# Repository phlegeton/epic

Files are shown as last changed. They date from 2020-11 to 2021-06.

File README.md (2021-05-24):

# The Extensible PI Cluster Frame  
This repository contains all the files for the The Extensible PI Cluster Frame  or **EPIC Frame**  

This cluster frame provides:

* Easy way if extending the frame
* Easy way of inserting / removing PI nodes from the cluster frame
* Each node can have proper cooling, by able to place heat-sinks on the PI nodes. 
* A special developed PI Cluster HAT provides addition cooling by PWM controlled FAN 
* A special developed PI Cluster HAT provides signal distribution across a backplane (Power 3.3V,5V,I2C)
* A special developed backplane provides power and signal (I2C) to each node
* A special developed LED board provides 3 RGB LED per node for status
* A special developed Power board provides the interface to the backplane 
* The cluster frame is extensible. The smallest frame consist of two nodes, and can be extended by 2 nodes (2,4,8,10)
* A Frame of 10 PI nodes fits into a 19" rack.

This cluster frame needs an external power supply. See the documentation directory for more information about power requirements.

This repository contains all the files to create the Cluster frame and PCB's. See the docs directory for more information and installation instructions.
In the tools directory you find tools which may be handy during assembly.

Note that:

**Current this project is in active development** 
which means that:

The design is still changing, and there are still changes being made. 

If you however want to help, and test things out or just want to give feedback:

Then **YES** put your 3D printer to work and test out the design!

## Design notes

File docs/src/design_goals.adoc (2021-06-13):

////
:imagesdir: assets/images 
:includesdir: include
include::./{includesdir}/document_settings.adoc[]
////
== Design goals
The cluster frame is designed with the idea of being as modulair as possible. This means that the minimal frame size is just for 2 nodes. This frame can then easily be extended into 4,6,8 or 10 pi's max if the frame needs to be 19" mountable. It's easy to stack 10 rows on Pi's in a rack. When extending the frame to more then 10 Pi's I'm not sure if the frame is strong enough to do this. 

That brings me to the second design goal: The whole design needs to be free to everyone who wants to build it, and it must be possible for everyone to adjust it to one needs. 

So this frame is ideal if you want to stack some PI's together. However if you need access to the GPIO pins, this frame might not be for you. The  GPIO pins are covered by a HAT which enables the PI cluster node to have proper cooling, and allows for three RGB leds. This frame intended use is for housing a PI cluster. And normally in a cluster setup the GPIO pins are not used. (in this case some of them are, for controlling RGB status LED's and a FAN for cooling).

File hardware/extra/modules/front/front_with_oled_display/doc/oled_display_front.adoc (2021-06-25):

== Installing the OLED front Display
The OLED display front can be attached to the PI tray in the same way as the original front. The OLED display to use is: OLED Display 0,91 inch 128x32 with a SSD1306 driver. This allows the use of the Adafruit OLED library for the Raspberry pi. 

To connect the display connector J5 can be used. The connections are: 

* pin 1 GND
* pin 2 3.3V
* pin3 SCL
* pin4 SDA

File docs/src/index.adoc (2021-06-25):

:toc:
:toc-placement!: 
= Extensible PI Cluser Frame - Hardware guide
Hades <hades@spacebugs.nl>
v1.0, 2020-28-11
//include::./{includesdir}/document_settings.adoc[]

//include::./include/documents_settings.adoc[]
include::include/document_settings.adoc[]

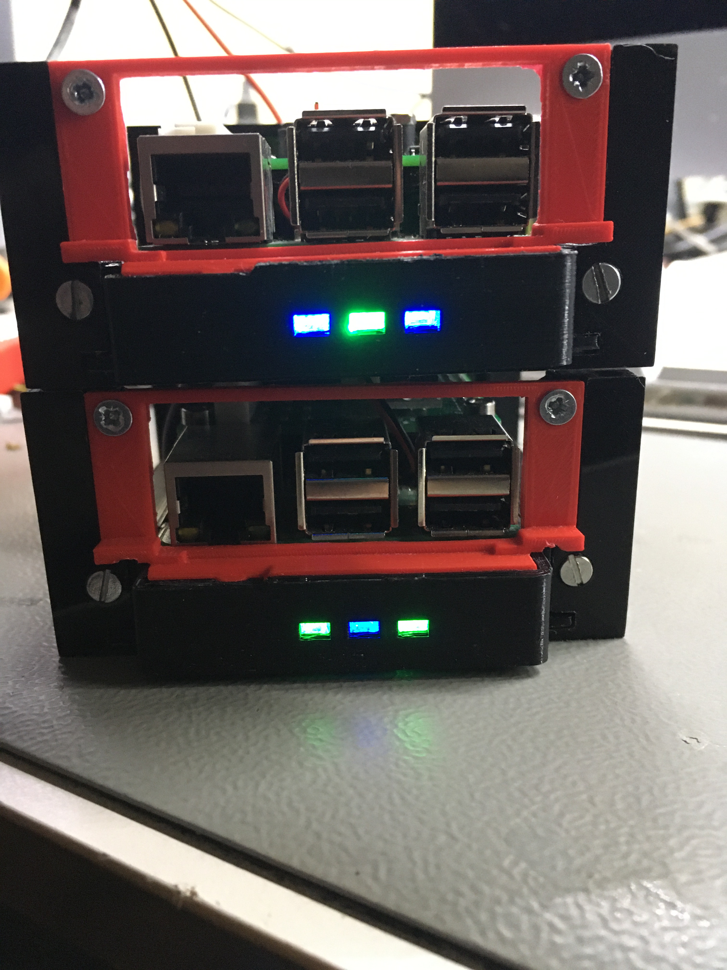
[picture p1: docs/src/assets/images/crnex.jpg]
Two node cluster


== Main index

toc::[]

include::introduction.adoc[]

include::a_word_about_license.adoc[]

include::design_goals.adoc[]

include::current_issues.adoc[]

include::roadmap.adoc[]

include::modules.adoc[]

include::3d_printing_the_parts.adoc[]

include::preparing_pi_tray.adoc[]

include::assemble_front_panel_with_bezel.adoc[]

include::Features_power_board.adoc[]

include::assemble_power_board.adoc[]

include::Features_PI_Cluster_hat.adoc[]

include::assemble_cluster_hat.adoc[]

include::Features_LED_board.adoc[]

include::assemble_led_board.adoc[]

include::assemble_pi_tray.adoc[]

include::building_cluster_frame.adoc[]

include::attach_backplane_cover.adoc[]

include::testing_pi_cluster_frame.adoc[]

include::parts_list_introduction.adoc[]

include::complete_parts_list.adoc[]

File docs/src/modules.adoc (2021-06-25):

== Modules
The whole design idea is to have a modular design. In the repository under the extra directory there is a modules directory. Currently only a front-end module exist. The idea of this directory is that its possible to add "third party" modules. For example it could be possible that someone comes up with parts for an alternative cluster frame. The modules directory can be used to place these modules. Which means the rest of the original cluster frame in the repository can be left untouched.

Each module directory must include a doc directory, explaining how to use / build etc. 

The current alternative front-end module allows one to add a oled display to the front-end instead of the RGB leds.

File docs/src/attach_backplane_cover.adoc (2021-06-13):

////
:imagesdir: assets/images 
:includesdir: include
include::./{includesdir}/document_settings.adoc[]
////

== Attaching the backplane cover
If the cluster frame is able to power all the PI nodes, the back-plane covers can be placed.

To attach the back-plane cover you need: 

- 1x XT60 connector 
- 2x M2.5x10
- For every back-plane you need one cover
- For every back-plane cover you need 4x M3x40 screw

=== Prepare the back-plane cover
One of the back-plane cover is holding the XT60 connector, so there is one 5V connection which powers the whole PI cluster: 

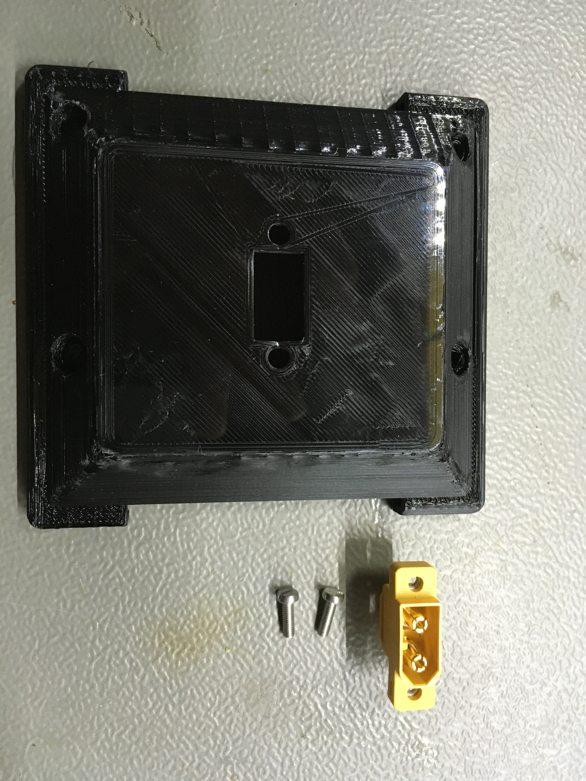
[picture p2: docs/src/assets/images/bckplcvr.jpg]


To attach the XT60 connector insert the XT60 connector from the back:  

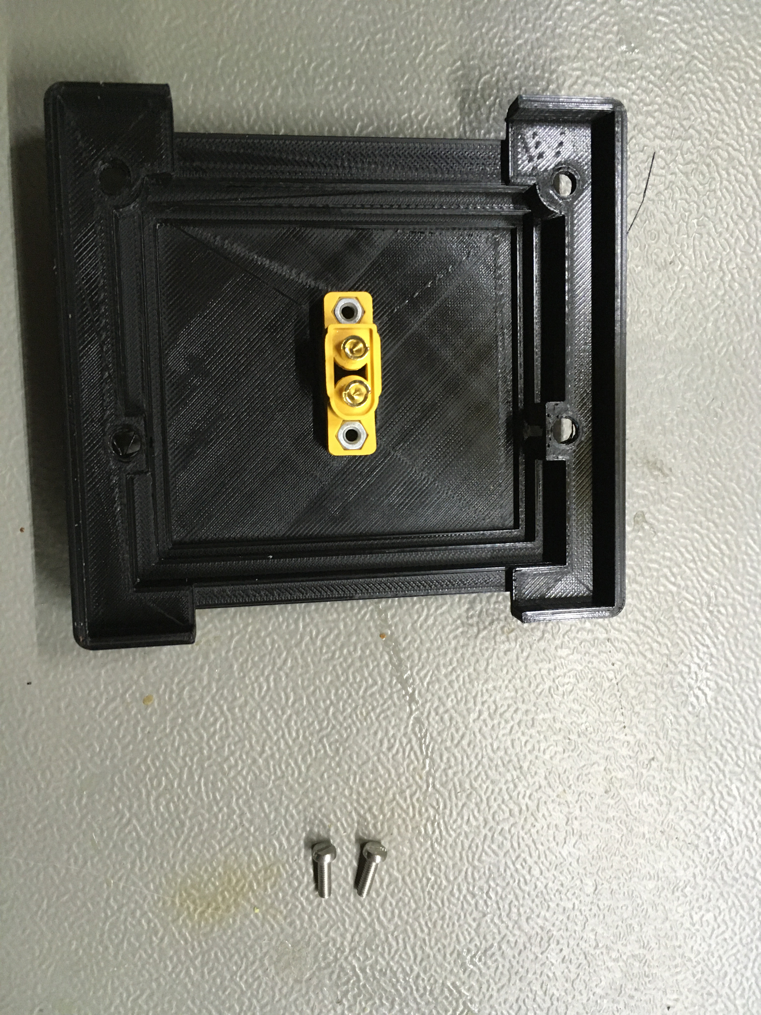
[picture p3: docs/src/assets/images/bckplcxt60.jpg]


Next insert the 2xM2.5x10 screws from the top: 

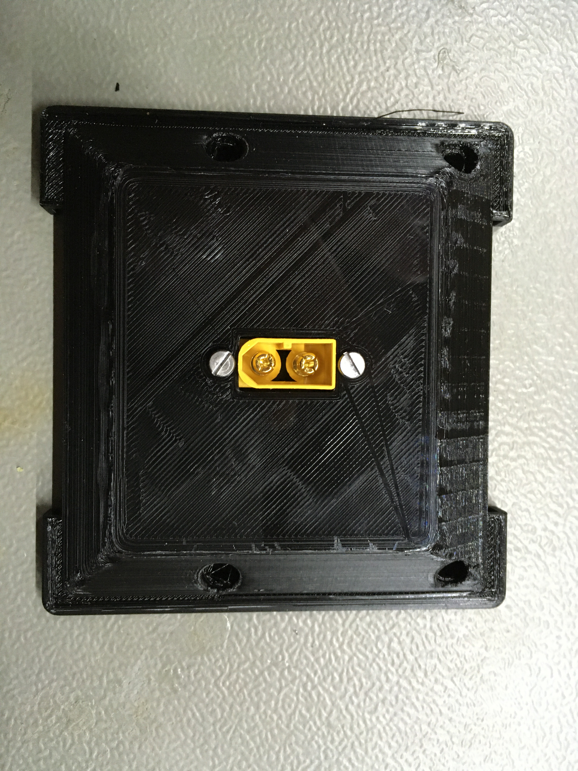
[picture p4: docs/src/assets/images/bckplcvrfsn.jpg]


=== Power connections
The backplane cover connects the power to the whole PI Cluster. So a cable is needed to connect the SMPS to the backplane. And from the XT60 connectors connections need to be made to the back-plane(s). See the discussion in the section <<Connecting the backplane>> about how to connect the back-plane(s)

If there are any test wires, remove them from the backplane. And attach the definite wires. When connecting the backplanes in parallel a wire like: 

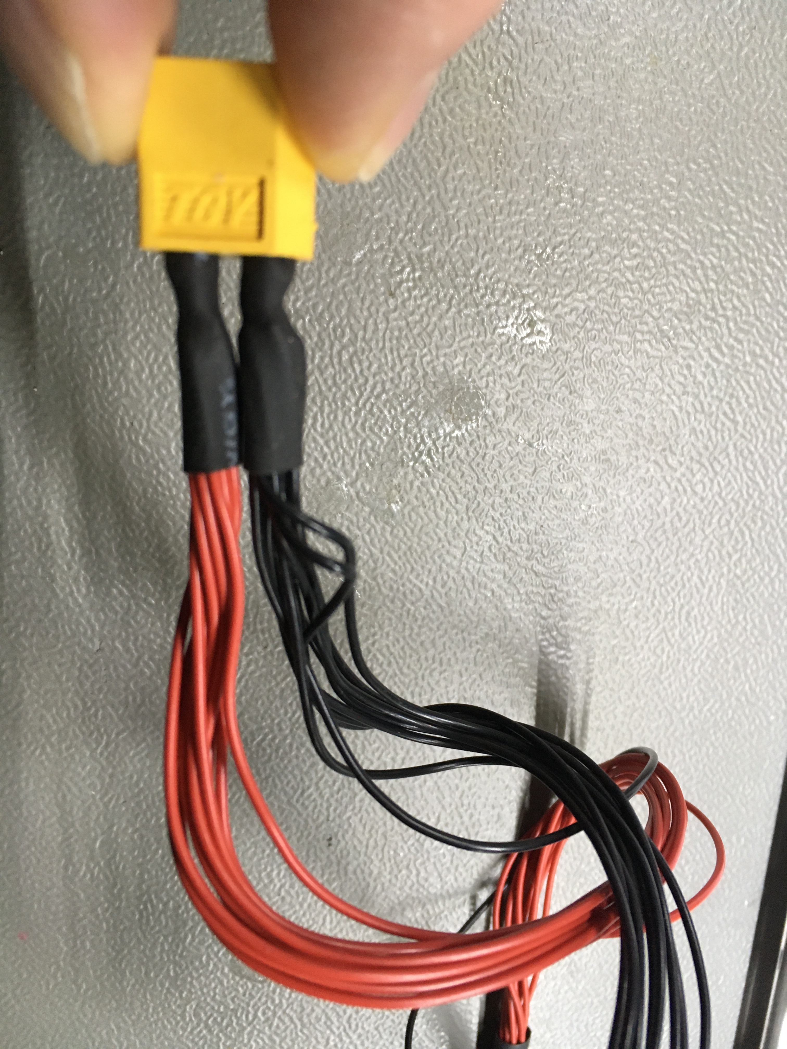
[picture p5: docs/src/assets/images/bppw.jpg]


Can be made (This is just a example) Each black/red wire pair is soldered to a backplane.

When using a two node cluster, solder the wires onto the backplane:

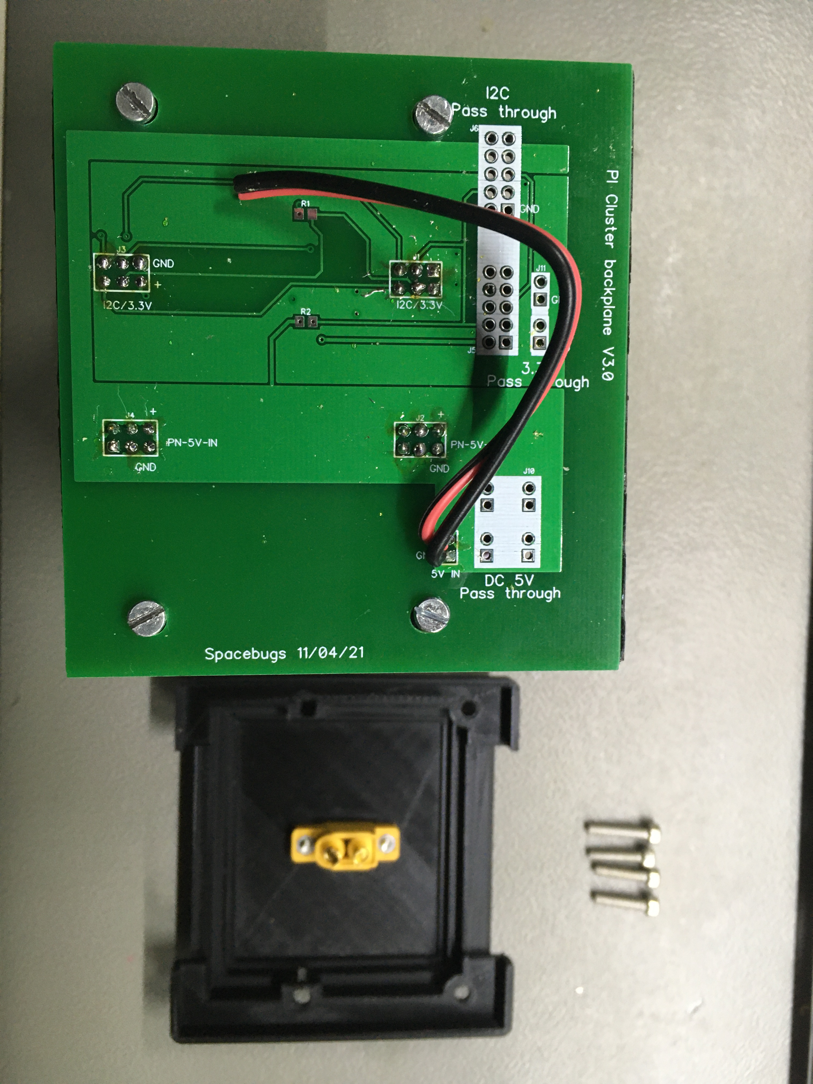
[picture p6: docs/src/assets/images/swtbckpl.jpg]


Once the wires are soldered onto the backplane connect the wires to the XT-60 connector. Make sure to get the polarity right!

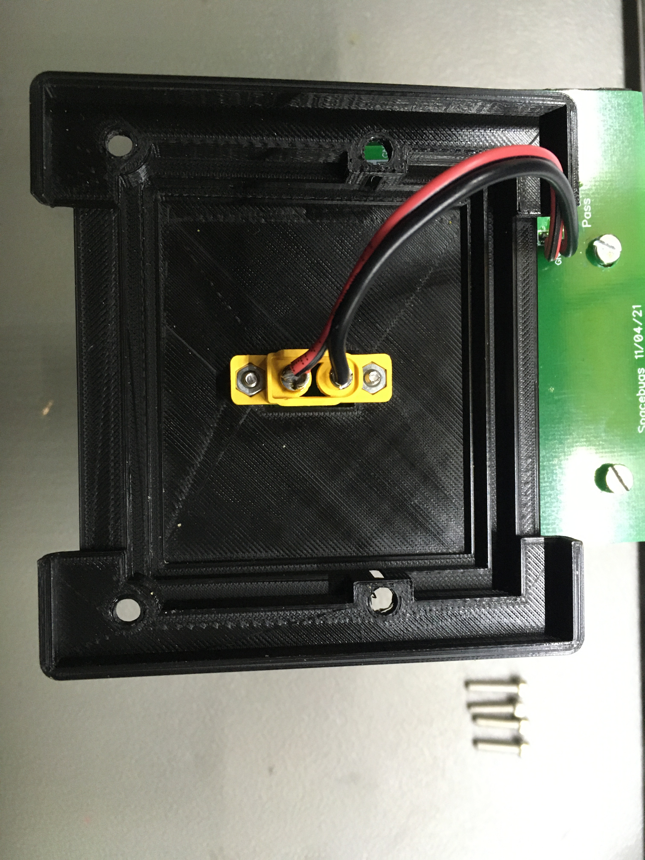
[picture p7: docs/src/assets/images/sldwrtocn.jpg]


=== Placing the back-plan covers
To place the the cover make sure all the PI nodes are powered off. And no 5V is applied to the chassis.

The easiest way to place the backplane covers is to place the cover, back-plane by back-plane: 

Unscrew the four temporarily screws:

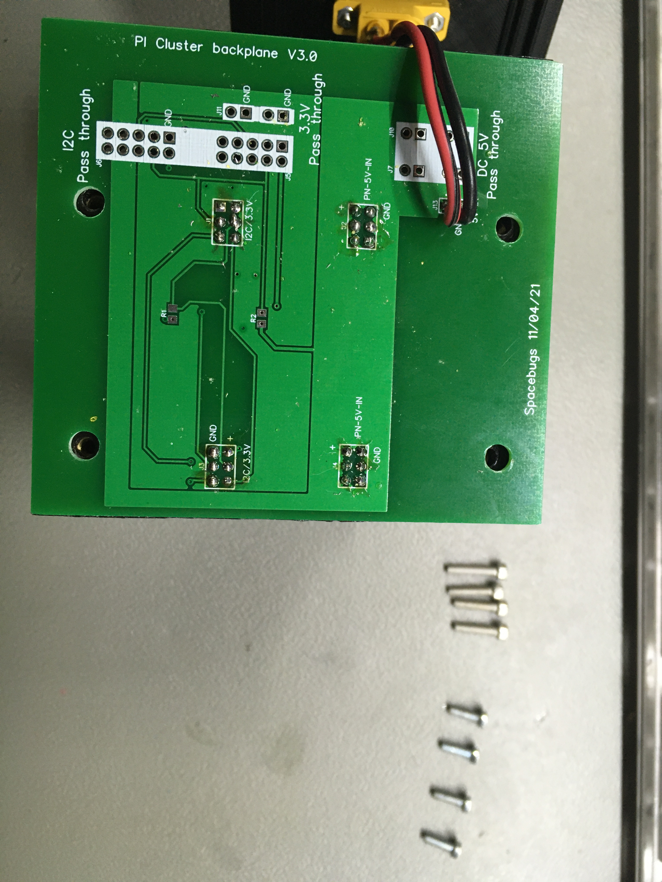
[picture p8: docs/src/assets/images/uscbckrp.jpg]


- Place the backplane cover
- Use 4x M3x40 screws to fasten the backplane cover

Repeat this for every back-plane

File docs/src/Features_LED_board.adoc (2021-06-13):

////
:imagesdir: assets/images
:includesdir: include
////
== Featues of the LED Board
The LED Board provides the following features:

- 3x RGB LED on a small PCB
- Easy connection to the PI Cluster HAT by using one JST XH 10 pins female connector 
- One common GND PIN for easy controlling the RGB LED's and save precious space on the PI Cluster HAT
- Easy and solid attachment to PI Tray

=== Theory of Operation
The LED Board holds 3 Common Cathode RGB LED's on a small PCB. The RGB LED's share a common GND. This reduces the number of connections needed from 12 connections to 10 connections, which save space on the PI Cluster HAT, and also save on the number of wires. 

NOTE: The silkscreen on the PCB has no GND or (-) marking. This is fixed in the next version of the PCB. The pin closest to the silkscreen marking "J1" is the common GND pin.

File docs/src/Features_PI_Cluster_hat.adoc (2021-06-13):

////
:imagesdir: assets/images
:includesdir: include
////
== Features of the PI Cluster HAT
The PI Cluster HAT provides the following features:

- 1x GPIO PWM Controllable FAN
- 3x GPIO PWM Controllable RGB LED's
- 5V Power Distribution
- 3V Power Distribution
- I2C distribution
- 1x Programmable I2C EEPROM
- 1x I2C Breakout
- Provides J6 ('WR-E') to program the EEPROM

The PI Cluster HAT distributes the 5V , 3.3V and I2C to the backplane. Although it's called a PI Cluster HAT, technically it's not a official PI HAT. This because the PI Cluster HAT doesn't met all the requirements. For instance, it doesn't have rounded corners, the hole sizes are not correct. However this is done with a reason, so it's fit better in the cluster frame, and makes assembly slightly easier, by taking 3D printer margins into account (for example) 

=== PI Cluster HAT Theory of Operation
This section explains the features of the PI Cluster HAT in more detail.

The PI Cluster HAT is designed with the PI HAT regulations and requirements in mind. However, some requirements are not met. In this section, this is addressed as well.

The PI CLuster HAT main purpose is to provide a PWM Controlled cooling FAN which is placed just above the Raspberry PI CPU, so the CPU is cooled in a very efficient way. 

=== Cooling FAN
The FAN is connected by a N-CHANNEL MOSFET to BCM pin 18. Which makes it possible to control the cooling FAN easily by software.  By using PWM the FAN speed can be controlled. This allows efficient cooling, reduces power consumption, and hopefully less FAN noise. 

To protect the MOSFET a fly-back diode can be added. However during testing, this seems not required. 

=== 5V Power
The second most important task of the PI Cluster HAT is to distribute power to the PowerBoard, making it possible to connected a Raspberry PI to a back-plane.

The PI HAT doesn't provide a diode to protect against reverse voltage polarity. So when testing the PI Cluster HAT outside the PI Cluster frame, make sure you wire it up correctly! The reason for not adding a diode, is to prevent the voltage drop caused by a diode.

The only risk of damage the Raspberry PI by reversing the 5V polarity, is when:

- Testing the PI node outside the cluster frame.
- When the power board or power wires are assembled incorrectly.

=== GPIO Features
Futhermore the PI Cluster HAT provides a means of using some of the GPIO pins/features, which normally won't be accessible once the Raspberry PI is inside the cluster frame. 

==== 3x software PWM controllable RGB LED's
By providing 3 RGB LED's which are PWN software driven, it's easy to control these RGB LED's from software as status LED's.
The RGB LED's can for instance be used as a power on LED, Temperature status, or any other status.

The PI Cluster HAT Provides current limiting resistors, to protect the GPIO PIN's and the RGB LED's as well.

==== I2C feature
The PI Cluster had provides a breakout connector for I2C, while I2C is also distributed across the backplane. The breakout connector is not used at the moment, but it could be used for hooking up a small OLED display for example (which means adjusting the the PI CLuster hardware). 

==== I2C EEPROM
The Raspberry PI provides an *separate* I2C bus from the GPIO pins to control a I2C EEPROM. This I2C bus *MUST* only be used for the I2C EEPROM! The PI CLuster HAT includes this EEPROM is as well. The EEPROM is programmed to provision the GPIO initial status, and controls the Power On LED. The contents of the EEPROM can be overwritten, by reprogramming the EEPROM, and writing an own overlay.

NOTE: The EEPROM is not necessarily for the operation of the PI Cluster HAT. The Power on LED is controlled by the EEPROM at boot time. However this can be done by an external script as well. 

The EEPROM has the required pull down resistors, as well as test points to control the Read and Write (R/W) signals.

NOTE: To be able to write to the EEPROM, the pins of J6 ('WR-E') must be shorted. Once the EEPROM is written, the short between the pins *SHOULD* be removed.

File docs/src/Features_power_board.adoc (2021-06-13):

////
:imagesdir: assets/images
:includesdir: include
////
== Features of the Power Board
The power board PCB provides the following features on a small footprint:

- Efficient power distribution
- Separated 5V and 3V connections
- I2C to backplane connection
- Low voltage drop
- Rated for 2 Ampere 

=== Theory of operation
The power board contains 2x female 2x3 headers which allows 5V distribution to the back-plane on one 2x3 connector, and the 2x3 connector allows for I2C connection and 3V power distribution. The Power board doesn't contain any active or passive components, other then tw 2x3 female connectors. 

Both the connectors must be aligned to the mating back-plane connectors to allow a low voltage drop connection.

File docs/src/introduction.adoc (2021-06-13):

////
:includesdir: include
ifdef::env-github[]
:tip-caption: :bulb:
:note-caption: :information_source:
:important-caption: :heavy_exclamation_mark:
:caution-caption: :fire:
:warning-caption: :warning:
endif::[]
////
Hades <hades@spacebugs.nl>
v1.0, 2020-16-11

== Introduction
Having some Raspberry PI's at your disposal is already fun. Turning them into a cluster is really fun. Well.. at least I think it's fun. This project started when a few years back a friend and I came to the elusive idea of building a 10 node cluster. We had our reasons to do so. The first and most obvious reason is of course to have fun. The other reasons were about learning something about clusters, and software deployment on a cluster. 

At that time this friend got a 3D printer, and he started to design and print a frame which could hold 10 Pi's. One day he stopped by dropping off the frame for the 10 PI's. The idea was to link those 2 set's of 10 PI's together over a VPN, and we would have access to a 20 node cluster, in two separate geographic locations. How cool is that ?

We played around with it for a while, starting to configure the infrastructure needed to manage the cluster, and started to deploy software on the cluster. There was however one thing we needed to address. And that was the cooling of the cluster. Long story short: we find ourselves in busy day jobs, no time to spend on the cluster, and slowly the cluster, and the idea disappeared on a shelf. As it so often happens. 

Till recently. Due to some new challenges I needed an environment of a couple of physical hosts. Something that would scale.. A couple of PI's would do nicely.. In other words I needed a cluster. And yes I got one, but for the tasks I had in mind, I needed to fix the cooling issue. So I tried to alter the current frame. After several tries I discovered altering the original design would result in a complete redesign, or start from scratch. And of course there was the other option: Looking around if someone else already had developed a PI Cluster frame. 

And I did find some online, which looks promising, but the all have the same problems: 

- Most of the PI Cluster frames relay on PoE, which I don't want to use (don't have a PoE switch, with enough ports)
- Cooling issues, none of the Frames provides a integrated solution to provide prober cooling, other then using a PI HAT
- Some solutions didn't provide the modularity I'm after.

Looking at the current solutions available I started thinking about: 

- Creating a Cluster PI HAT, which would not only provide a way of cooling the PI node, but also provides power distribution.
- Another thing I likely need is to share a I2C bus between the nodes. This PI Cluster HAT could also take care of that.
- I also wanted some status LED's per node. Most likely RGB LED's so I could make 3x3 types of "signals" For example 'temp, cpu, power on'.
- And I really want a central power management module to power on/off nodes, which would 'remember' the power state of the nodes.

So basicity this means: Starting from scratch. However this was not something I wanted to do. And for good reasons: I needed a cluster quickly. Second, designing from scratch means a lot of work, and I already got a lot of projects on my hands. There was one thing however. I got this idea for really long time. And now I have the opportunity (I mean ultimate excuse) to realise this idea. This idea is about designing a backplane I could plug the PI's into. For some reason (and don't ask my why) a have fascination for backplanes. 

Long story short I started on the 5th of june 2020 to design a cluster frame that would: 

- Makes it possible to easy swap PI's
- Easy to maintain
- Relativity simple to build
- Hold 10 PI's in a 19" rack-able frame (But also should provide smaller cluster frames)
- Open Source, everyone should be able to build, alter, share this cluster frame.

Of course I had a lot of more requirements, but these were the essential ones.  During the development of this cluster frame I learned a lot. One of the things I needed to guard myself against was the phenomenon I like to call "feature creeps". Once I start designing it's oh so tempting to put in every possible thing that makes the project more feature rich, and of course all those features are "must haves". So right from the start I created a "requirements document". It's a few pages long, but in essence I could rewrite the whole document into one sentence:  

"Don't allow for any feature / aspect to slow the project down, or prevent it from coming up with a working proof of concept (PoC)".  

And even with such requirement document, it's hard to put great ideas about features aside.

But eventually I managed to just move forward, and even when somethings aren't perfect, or even won't work as intended I build a PoC in less then 3 months. Spending most of my evening and weekend to design and build this frame. 

The end result is that I designed 3 PCB's for the cluster frame: 

- PI Cluster HAT (Which provided, cooling and distribution of signals between the nodes)
- Power Board (Which is the "interface" which plugs into the backplane)
- LED Board (Which holds 3 RGB Led's)

All in all this design might require more parts to assemble and might be more complex then the other solutions out there. However It does exactly what I need, and makes maintaining and scaling a cluster of PI's really easy. And I hope it might be useful to someone else.

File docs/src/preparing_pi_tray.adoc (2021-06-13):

== Preparing the PI Tray
////
:imagesdir: assets/images
:includesdir: include
include::./{includesdir}/document_settings.adoc[]
////
include:include/documents_settings.adoc[]
The PI Tray is responsible for holding several components:

- The Raspberry PI itself
- The PI Cluster HAT + cooling FAN
- The Power board 
- The LED board
- The front plate
- The front bezel 

To coop with all of this, the PI tray needs the be prepared by inserting some brass press inserts.
There are several options:

- Use 4x M2.5 brass press inserts to mount the Raspberry PI
- Use 7x M3 brass press inserts to mount the rest of the components

or:

- Use M2.5 brass inserts for every thing. 

Both options will work, as long the brass press inserts require a hole of +/- 4mm (And they should)

In this document the 'puristic' path is chosen and is using M2.5 and M3 brass inserts, just because it can and this is how the design was intended. Of course the downside of this approach is that more different type of screws are needed, which can be more expensive, and may make maintenance harder, since different screwdrivers are needed.

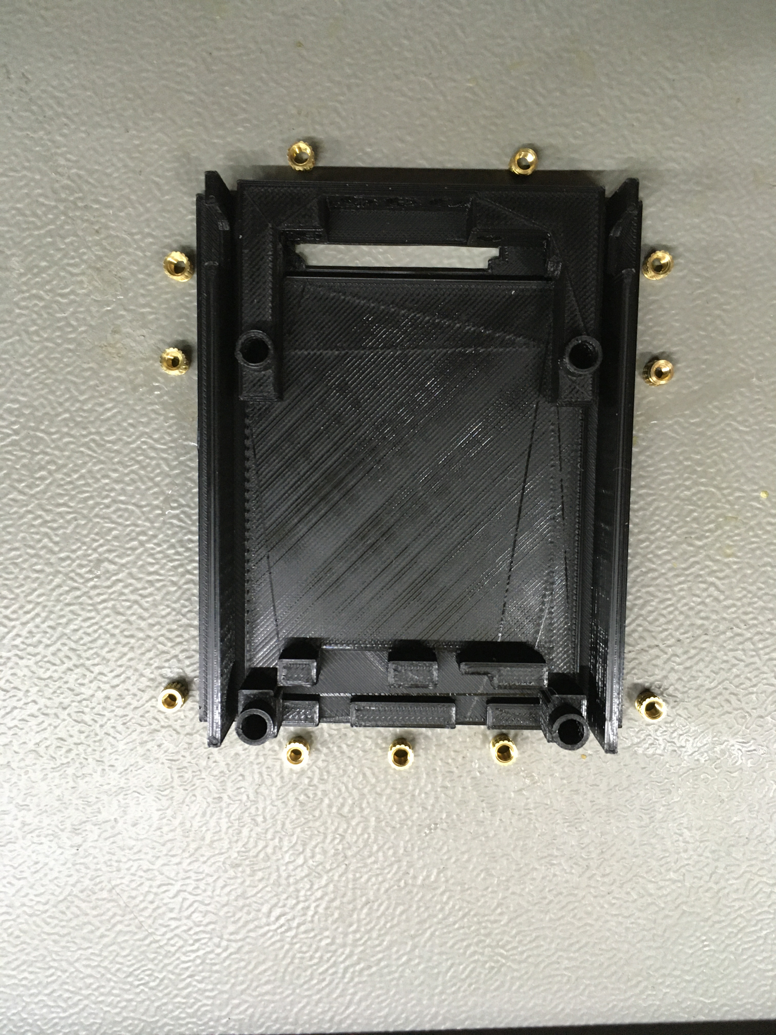
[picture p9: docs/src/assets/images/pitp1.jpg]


The easiest way of prepare the PI Tray is to start with the M2.5 brass inserts, by inserting them into the 4 holes and press them in the four holes by using a hot soldering iron. 

Next the M3 brass inserts can be inserted. Make sure not to melt the PLA when inserting the brass press inserts for the power board. And alo keep in mind, the brass press inserts for the LED board are inserted from the front. Trying to this the other way around, will for sure damage the PI Tray beyond any repair. 

TIP: Use a long screw (for example a M3x20mm) to position the brass press inserts. Just insert the screw one thread, so the screw can be easily removed.

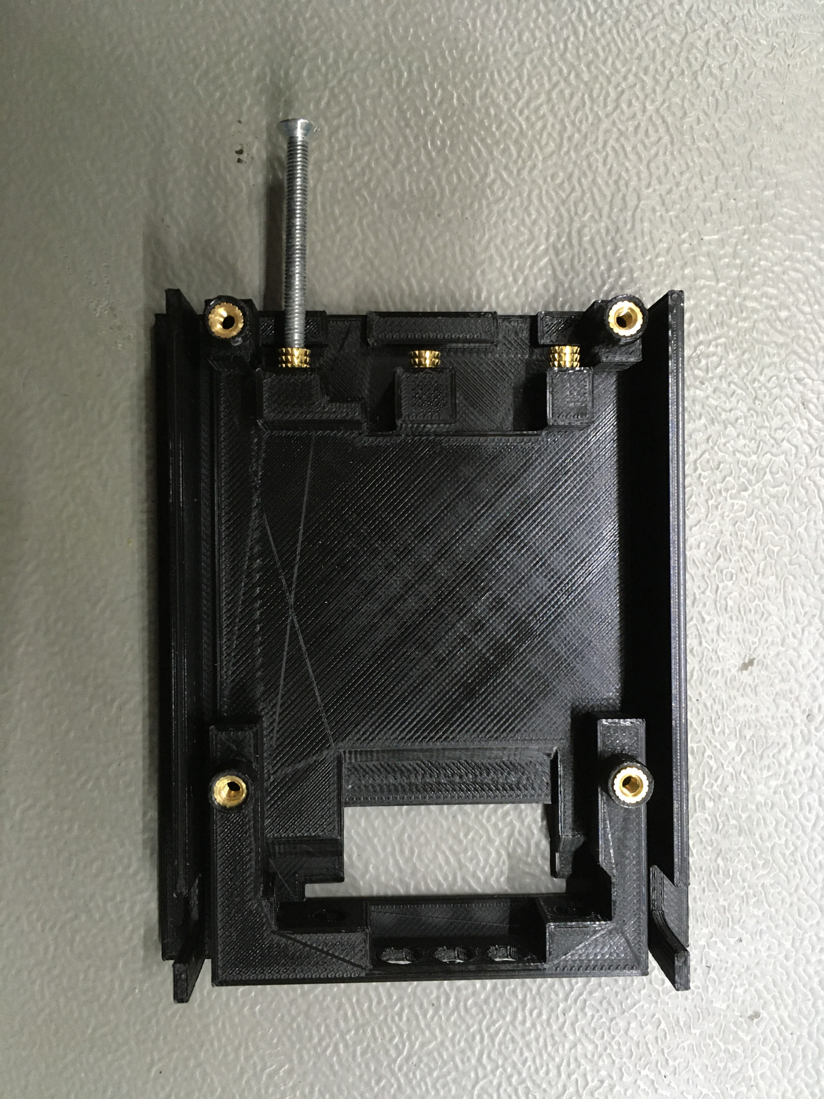
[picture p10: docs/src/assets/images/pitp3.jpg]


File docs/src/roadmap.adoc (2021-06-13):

////
:imagesdir: assets/images 
:includesdir: include
include::./{includesdir}/document_settings.adoc[]
////

== Roadmap
Currently the focus of the project is to get a minimal full working PI Cluster Frame. This means a few features are postponed, or new ideas are being put on a wishlist. To keep track of these postponed features and wishes, they are listed here. Implementing these features means that components of the PI Cluster Frame are going to be changed. And there is no intention to try to keep things backward compatible. This will slow the project down, and is almost not doable.

== Features postponed
- Be able to power down nodes, and keep the power status, even when the whole cluster is powered down. Implementing means possible change to back-plane. 

== Wish list
- Be able to connect a serial terminal to each cluster node. Implementing this causes the back-plane PCB to change, and the front bezel of PI Tray 
- Have different front bezels so one can use a OLED display instead of RGB LED's (for example)

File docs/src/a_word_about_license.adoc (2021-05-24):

=== A word about license
This Frame cluster and PCB's are free to everyone to use share and alter. Since I use closed source programs, like Fusion 360, Diptrace (for schematic, and PCB's) I cannot call this true open hardware. Therefore this PI Cluster Frame is licensed under a Creative Commons Attribution Share-Alike license. 

You can find the license here: http://creativecommons.org/licenses/by-sa/3.0/

Also see the license file LICENSE.TXT in the root of the repository.

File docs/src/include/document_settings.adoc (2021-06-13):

:fullWidth: 245
:fullHeight: 150 
:development_version_beta: 0.99 (Internal release Hades 2.0)
:current_version: 1.0
:safe-mode-level: 0
//:imagesdir: assets/images
:imagesdir: ../images
:includesdir: include
ifdef::env-github[]
:tip-caption: :bulb:
:note-caption: :information_source:
:important-caption: :heavy_exclamation_mark:
:caution-caption: :fire:
:warning-caption: :warning:
endif::[]

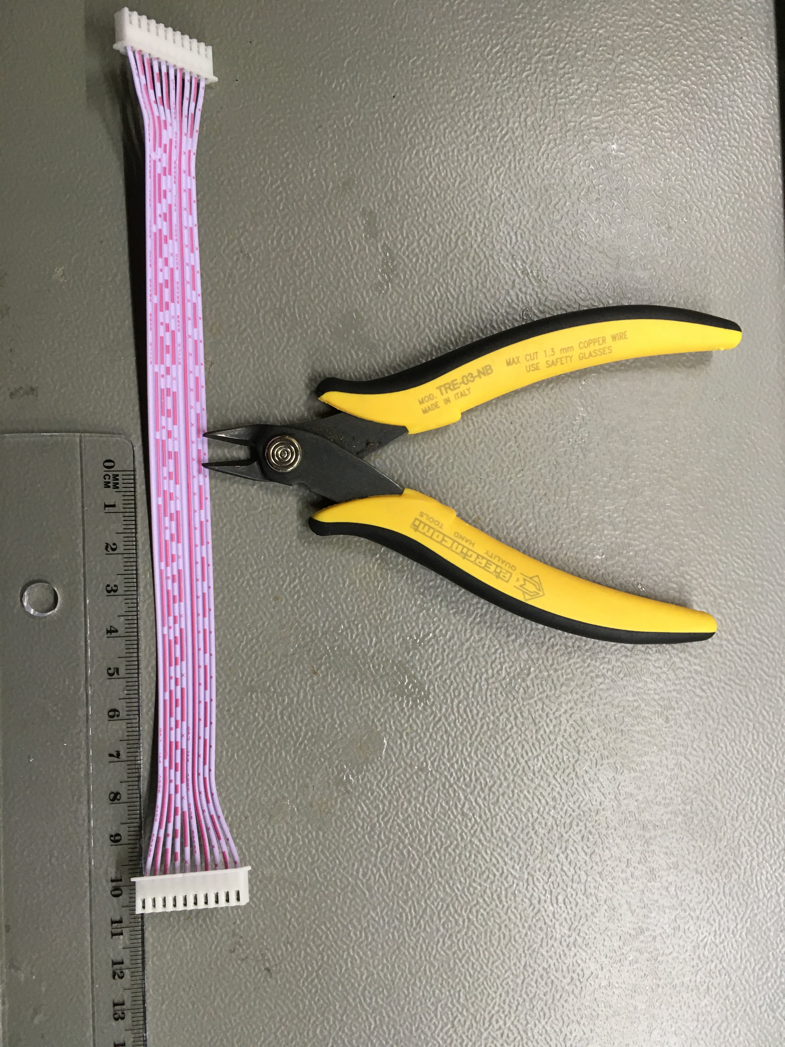
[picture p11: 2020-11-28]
docs/images/asrgbcbl.jpg

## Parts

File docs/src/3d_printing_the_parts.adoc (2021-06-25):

== 3D printing the parts

=== Print material needed
To print the parts regular PLA can be used. To print the light-pipes transparent PLA is needed.

=== Printing support
Some of the parts have support parts, these can be recognized by their yellow color.  Other parts needs support as well during printing, but don't have support built-in. To make sure that such parts are printed correctly, make sure that support is enabled in the slicer. For instance in Cura make sure to enable "support from print bed"

Parts with build in support have a gap of 0.15mm which should be enough to break away the support part easily. However, did may depend on your 3D printer. If needed adjust this to a wider gap.

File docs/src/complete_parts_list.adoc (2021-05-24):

== Complete Parts List
NOTE: List is provided AS IS. List may contain errors.

=== PI Tray
Parts needed to build 2 Pay tray's and 1 PI Cluster frame (which holds 2 PI's)

==== Hardware
- 2x Raspberry PI 3 or 4
- 8x M2.5 THREADED SOLID BRASS BARBED INSERTS FOR PLASTIC,PRESSFIT
- 18x M3 THREADED SOLID BRASS BARBED INSERTS FOR PLASTIC,PRESSFIT
- 8x M2.5x25
- 14x M3x5
- 8x M3x10
- 8x M3x14 
- 8x M3 nut

==== PCBs
- 2x Fully assembled PI Cluster HAT
- 2x Fully assembled PowerBoard 
- 2x Fully assembled LEDBoard

=== PI Cluster HAT
Parts needed to assemble 2x PI Cluster HAT

==== Electronic Components
- 18x SMD 0805 330 Ohm resistor
- 2x SMD 0805 1K Ohm resistor
- 4x SMD 0805 3.9K Ohm resistor
- 2x SMD SOIC-8 CAT24C32 EEPROM
- 2x SMD SOT-23 NDS351N Logic Level Mosfet
- 2x Litle Fuse  SMD 1206
- 2x 1x 25x25 5V FAN with 2 pins JST XH 2.54 connector 
- 2x JST XH 2.54 10 PINS connector
- 4x JST XH 2.54 2 PINS connector
- 2x JST XH 2.54 90 degree angel JST XH 2.54 10 pins connector + 10CM cable (pre crimped)
- 2x JST XH 2.54 straight JST XH 2.54 2 pins connector + 10CM cable (pre crimped)
- 2x SparkFun GPIO 2x20 Female header

NOTE: Recently the NDS331N became obsolete. Replacement: SSM3K344R, package is different (SOT-23F-3). Same footprint as SOT23

==== PCB

- 2x PI Cluster HAT PCB

=== Power Board
Parts needed to build 2 Power Boards

- 4x 2x3 rows 2.54 pitch female header
- 2x Pre-crimped JST XHT 2.54mm connector 

==== PCB

- 2x Power Board PCB

=== LED Board
Parts needed to build 2 LED Boards:

- 6x RGB LED 5MM
- 2x JST XHT 2.54 10 pins connector pre-crimped.

==== PCB

2x LED Board PCB

=== 1x PI Cluster Frame 
One PI cluster Frame holds 2 PI trays

==== Hardware
- 12x M3 THREADED SOLID BRASS BARBED INSERTS FOR PLASTIC,PRESSFIT
- 4x M3x10
- 4x M3x40
- 4x M3 threaded rod 
- 4x M3 nut

NOTE: rod length based on the number of PI frames. Max 19" for 5 PI frames (10 nodes) For 1 PI frame (which holds 2 PI nodes) rod length is +/- 90mm

==== PCBs
- 1x Backplane

==== Electronic Components 
- 2x 2x3 male header 
- Enough thick isolated copper wire to connect the backplane + 5V power supply

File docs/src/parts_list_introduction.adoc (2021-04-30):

== Parts List introduction
The complete parts lists contains per main components the parts needed. 
The main components of the PI Cluster frame are:

- PI Cluster Frame
- PI Tray

Per main components the list is divided into 

- Hardware 
- PCB
- Electronic parts needed. 

The lists contains all the parts which are needed to build the intended design. However, the design is modular and flexible. Which means there are more then one way to build the PI cluster frame.

For example: 

- Not using any connectors, and solder the wires directly to the PCB's. 
- Instead of using M2.5 screws, M3 screws can be used, by filing out the Raspberry PI mounting holes. 
- Instead of using M2.5x25mm bolts, M2.5 stand-offs with screws can be used to mount the PI Cluster HAT onto the Raspberry PI

The complete parts list however doesn't take these variants into account.

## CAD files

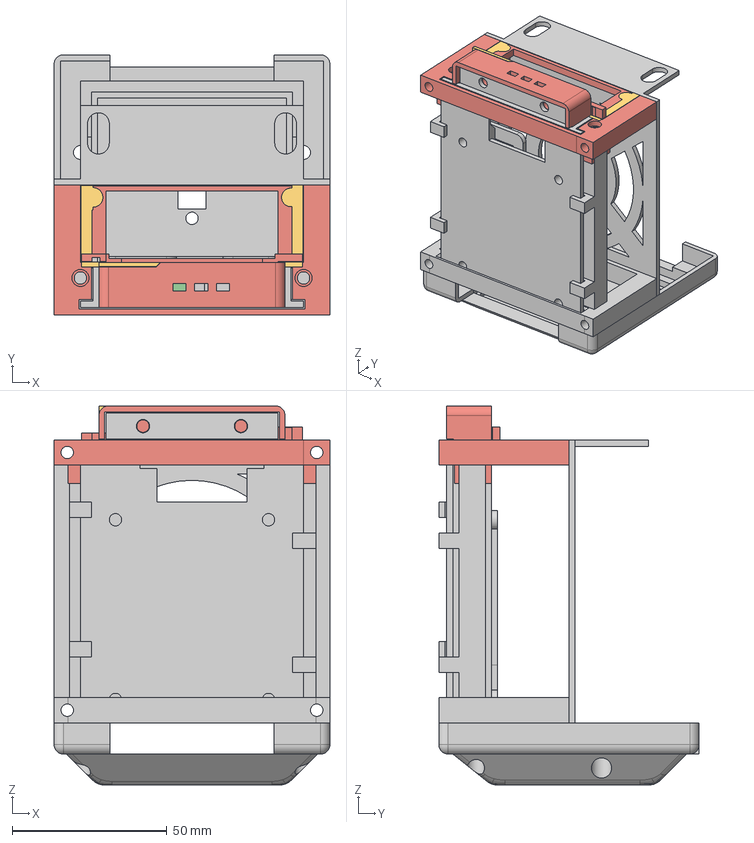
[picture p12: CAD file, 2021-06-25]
hardware/cluster_frame/step/Extensible_PI_Cluster.step
89.0 x 84.0 x 122.3 mm
pi-tray
fan holder
connecting rods
housing backplate
bracket
backplane cover
front-bezel-lightpipe-holder
light-pipe
front-plate
housing frontplate
front-bezel

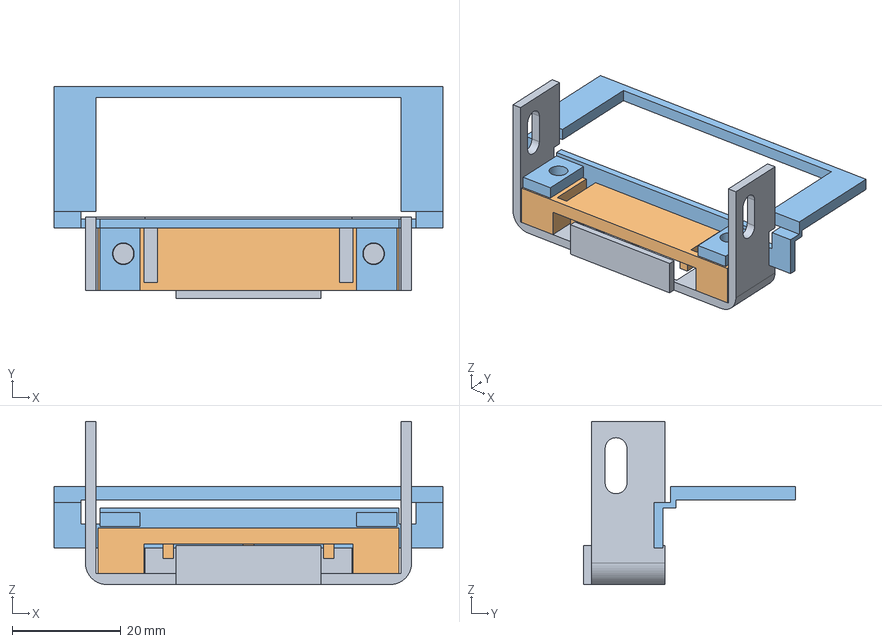
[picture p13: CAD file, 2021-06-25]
hardware/extra/modules/front/front_with_oled_display/step/front_with_oled.step
71.5 x 39.0 x 30.0 mm
front_bezel
bezel_inner_holder
front_plate

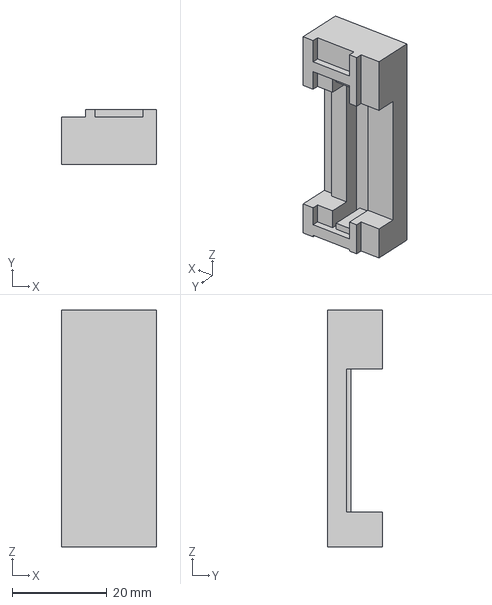
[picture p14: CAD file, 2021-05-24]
hardware/extra/tools/step/RGB_board_solder_helper_tool.step
20.0 x 11.6 x 50.0 mm

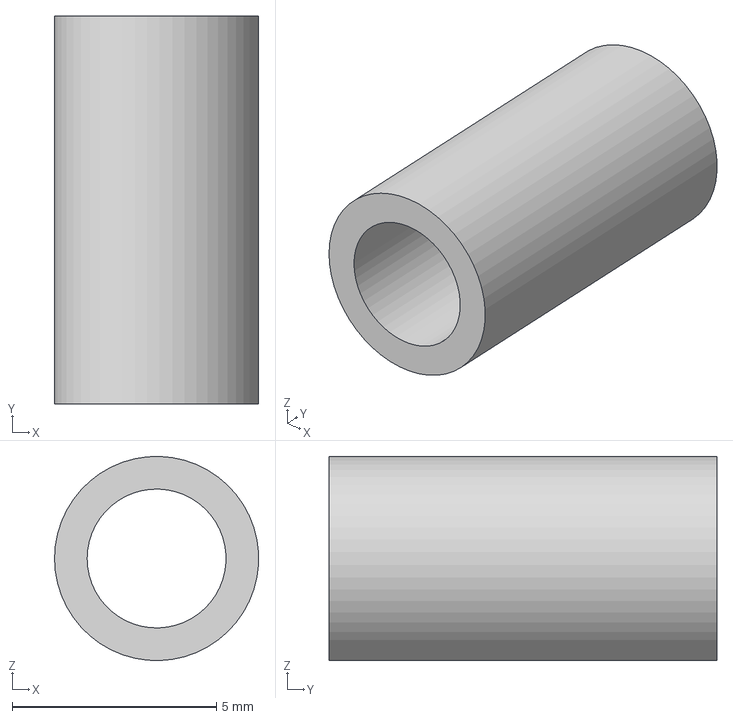
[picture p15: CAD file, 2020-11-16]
hardware/cluster_frame/step/spaces_between_pi_hat.step
5.00 x 9.50 x 5.00 mm

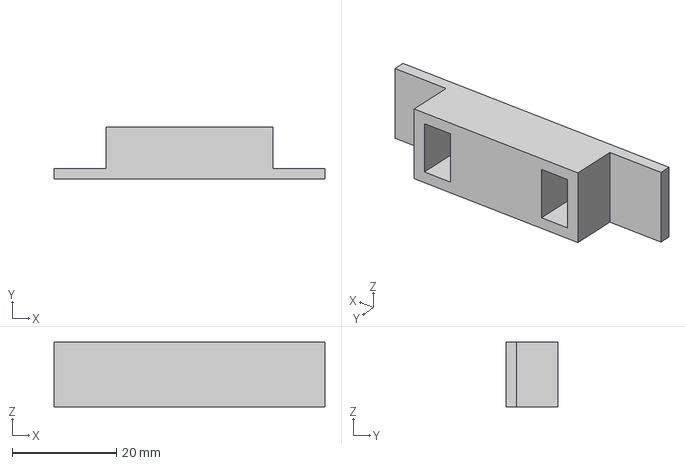
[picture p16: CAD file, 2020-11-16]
hardware/extra/tools/step/power_board_solder_template.step
52.0 x 10.0 x 12.4 mm

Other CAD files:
hardware/cluster_frame/Extensible_PI_Cluster.f3d
hardware/cluster_frame/spaces_between_pi_hat.f3d
hardware/extra/modules/front/front_with_oled_display/front_with_oled.f3d
hardware/extra/tools/RGB_board_solder_helper_tool.f3d
hardware/extra/tools/power_board_solder_template v3.f3d

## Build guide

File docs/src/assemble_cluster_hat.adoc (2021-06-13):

== Assemble the PI Cluster HAT
////
:imagesdir: assets/images 
:includesdir: include
include::./{includesdir}/document_settings.adoc[]
////
The PI Cluster HAT PCB contains SMD parts and also Through Hole parts. It may require some skills to solder these SMD parts, but it shouldn't be too hard to do, since the SMD package size is rather large (SOT-23-3 and 0805). 

Per PCB you need: 

- 9x SDM 0805 330 Ohm resistor (R2 - R10)
- 2x SMD 0805 3.9K Ohm resistor (R12,R13)
- 1x SMD 0805 1K Ohm resistor (R11)
- 1x SMD 0805 100nF capacitor (C1)
- 1x BAS 16 diode (might not required)
- 1x 2 Amp SMD 1206 fuse 63V 2A Slow blow
- 1x CAT 24c32 EEProm (not required)
- 1x NDS351N MOSFET (SMD sot-23-3) 
- 1x 40 pins GPIO header
- 1x 6 pins box header (for the I2C breakout connector). (not required)
- 1x 2 pins 2.54 male connector to program the EEPROM (However this also can be a piece of solid wire, so below)
- 1x 2 pins 2.54 female jumper (However if a wire link is used, not needed)

Depending on how you connect everything to the PI Cluster HAT:

- Solder the wires directly onto the PCB
- Use connectors

When using connectors you need the following:

- 1x 10 pins JST XH 90 degree angle PCB connector
- 2x 2 pins JST XH 90 degree angle PCB connector

NOTE: These connectors are often called "JST XH 2.54". However the pitch is really 2.5. This is normally not a problem, and fits in a 2.54 pitch.

The pro of soldering the wires directly to the PCB is the low profile. The downside is of course that when removing or when needing to replace a part, the wires needs to be de-soldered. 

When using connectors, all the connections can easily be disconnected. Which makes maintenance much easier. However, it costs more.

Whichever solution you choose, it doesn't matter, as long as the profile of the PCB is as low as possible. As a guideline: nothing should stick out above the FAN. When using for example straight connectors, the profile get to high, and the PI tray won't be able to slide in or out of the PI Cluster Frame. 

=== Enable EEPROM write mode
To be able to program the EEPROM, the EEPROM must be writeable. To do this the pins on J6 ('WR-E') must be shorted. This can be done by soldering a 2 pins 2.54 male connector. Or simply by soldering a wire link. 

To pro of using two pins 2.54 male connector is that it's easy to place a jumper across the pins, which is easily be removed once programming of the EEPRON is done. However the 2 pins are somewhat in the way of the FAN connector, making it a bit trickier to connect the FAN. 

By using a wire link, the pro is that the FAN is easy to connect, however, once the link is cut, it might be more difficult to short the link again, to reprogram the EEPROM.

=== Soldering the PCB
When starting to solder the PCB, first start with the SMD components:

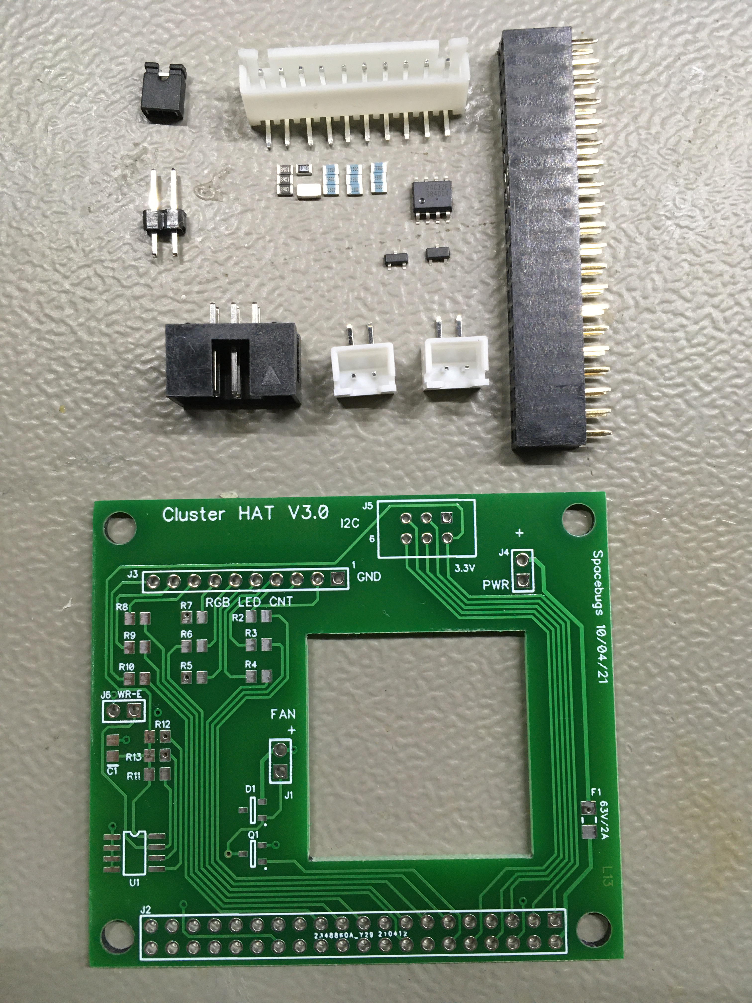
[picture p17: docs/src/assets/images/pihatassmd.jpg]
Components needed for PCB assembly{fullWidth}


Next solder the JST XH 2.54 haeders onto the PCB

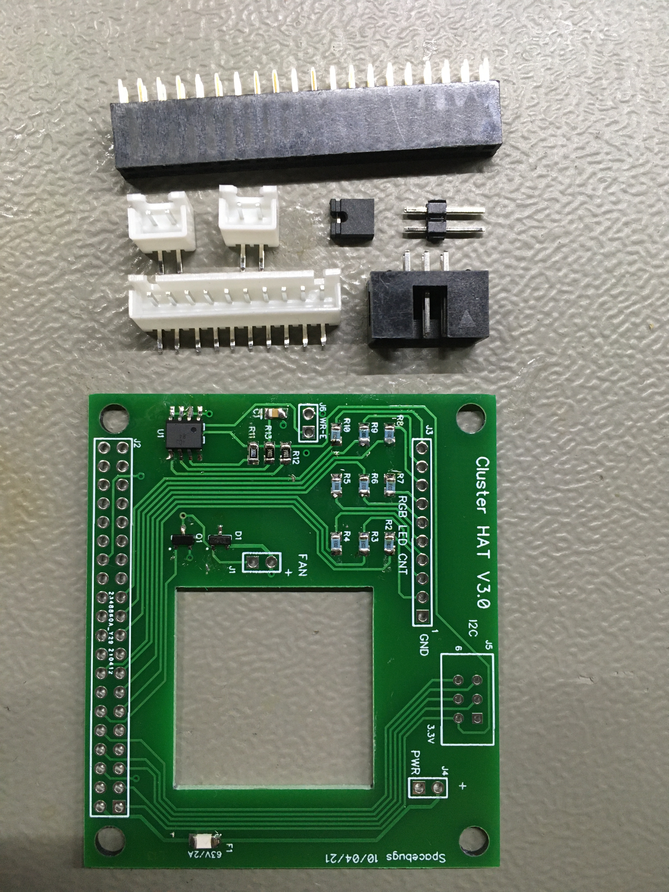
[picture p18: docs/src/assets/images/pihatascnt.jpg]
Solder the connectors


As a last step solder the 6 pins 2.54mm header, and then the as the last component the 2x20 GPIO pin header at the other side of the PCB. 

Tip for soldering the GPIO header: To make sure soldering the header straight, to PI Cluster HAT can be temporarily mounted onto a Raspberry PI, using the plastic mount stand-offs.   

The final PCB is shown below. In a last step the FLUX must be cleaned up from the PCB. But apart from that, this is how the finished PCB should look like.

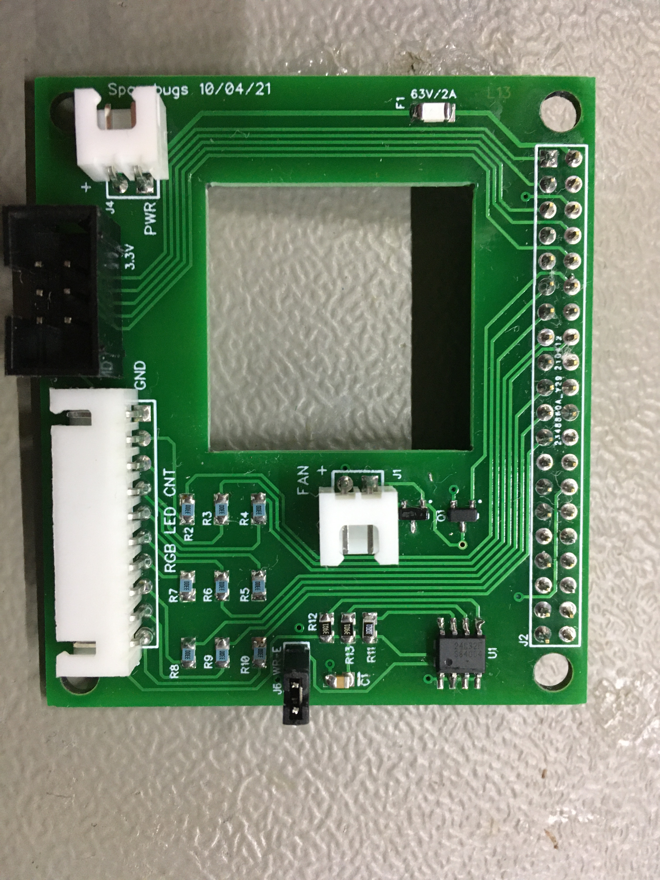
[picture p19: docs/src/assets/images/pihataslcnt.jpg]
Final PCB assembly


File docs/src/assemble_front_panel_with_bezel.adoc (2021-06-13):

== Assemble the front panel and bezel
////
:imagesdir: assets/images
:includesdir: include
include::./{includesdir}/document_settings.adoc[]
////

To assemble the front panel and bezel with 3 light pipes, the following is needed:

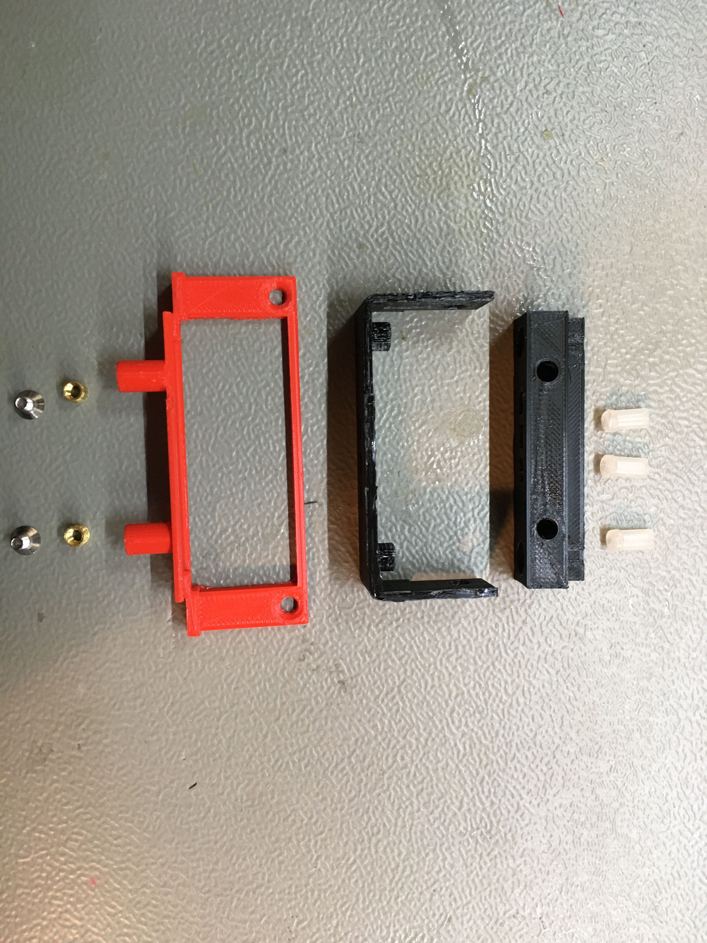
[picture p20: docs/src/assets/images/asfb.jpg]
Components needed for PCB assembly{fullWidth}


To assemble the front panel and bezel, the following parts are needed:

- 3D printed front panel
- 3D printed light-pipe holder
- 3D printed bezel
- 3x printed light-pipe (Need transparent PLA)
- 2x brass M3 press insert
- 2x M3x5 bolt 

=== Inserting the light-pipes
Start by inserting the light-pipes into the light-pipe holder:

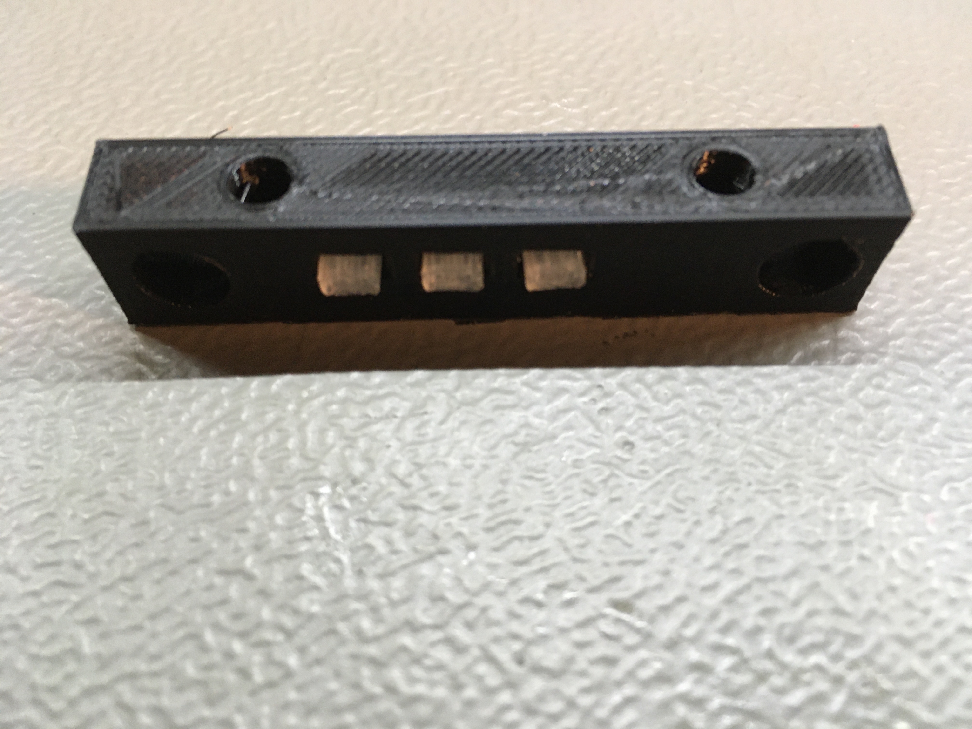
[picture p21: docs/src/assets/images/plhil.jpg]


The light-pipes are pressed in gently from the side with the round holes. After inserting the light-pipes, the light-pipes will stick out a few millimeters.

=== Pressing in the brass inserts
The brass press inserts needs to be inserted into the front panel. Make sure to align the brass press inserts as straight as possible. 

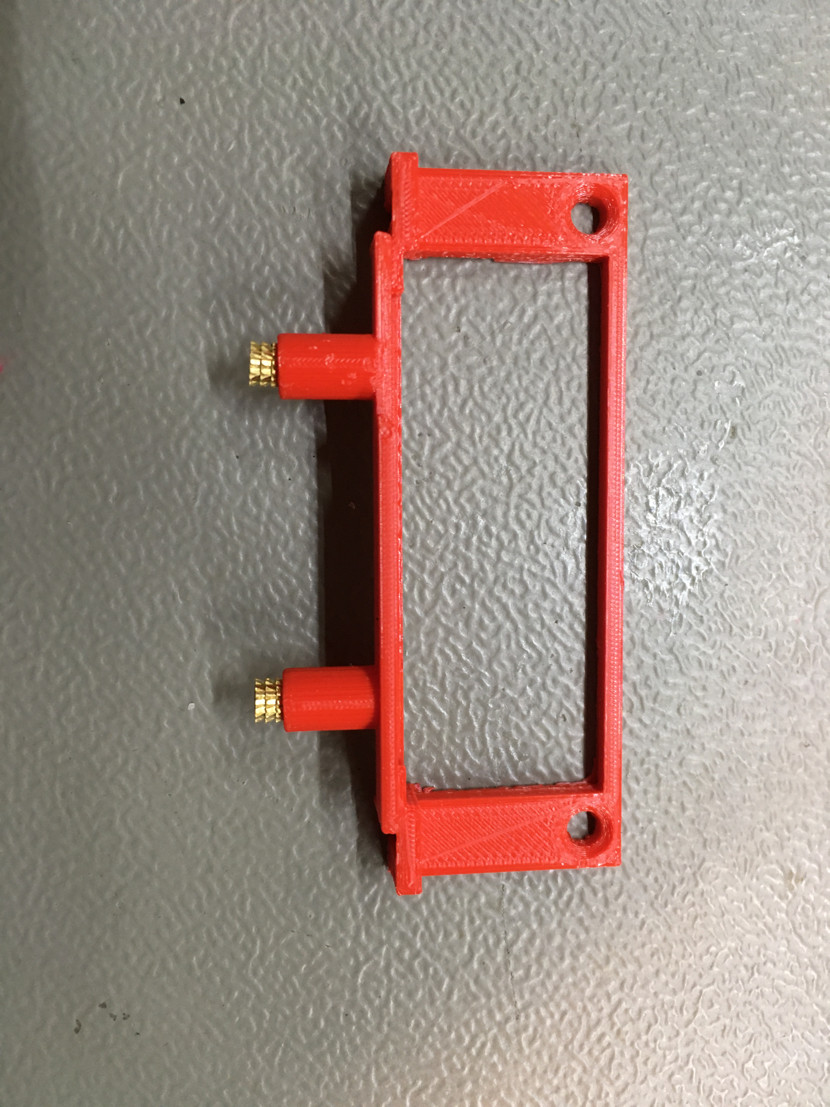
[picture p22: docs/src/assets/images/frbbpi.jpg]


=== Insert the light pipe holder into the bezel
Press the light-pipe holder gently into the front bezel. The light-pipes should align with the square holes in the front bezel. Look at the image below for the right orientation. The overhanging part of the light-pipe holder is on top. This overhang part, will prevent light from escaping ones it is mounted on the PI Tray.

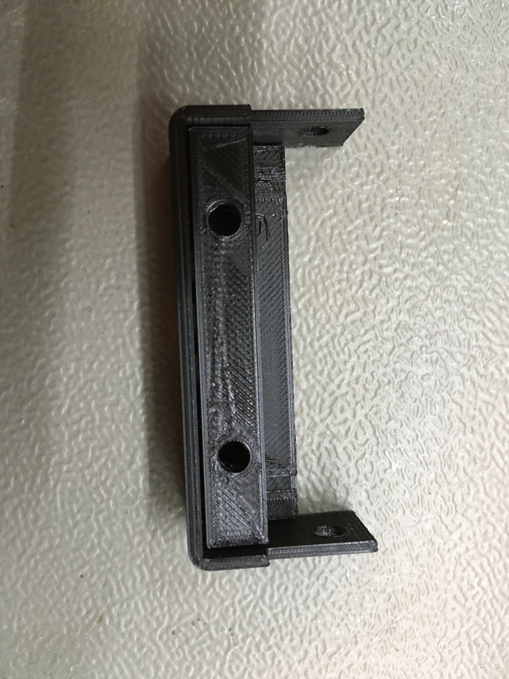
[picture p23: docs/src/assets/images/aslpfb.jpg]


=== Mount the front panel 
The last step is to mount the front panel onto the bezel assembly. Align the two mounting posts of the front panel with the hole large holes in the light-pipe holder, while the overhang on the light-pipe holder is on top. In other words, the little cut-out in the front bezel is upwards. This is a tight fit, and may need some force to push the front panel into place. Don't push to hard, since this may break something. If it doesn't fit, check if the front-panel is inserted correctly, and that the holes in the light-pipe holder don't hold any supporting material that needs to be removed. 

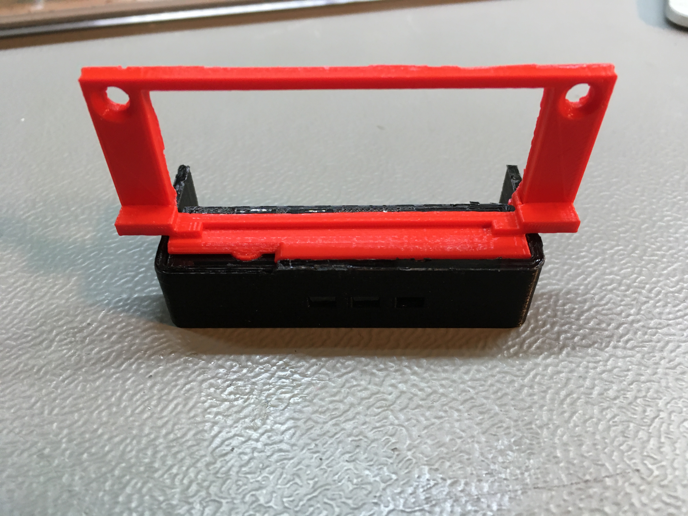
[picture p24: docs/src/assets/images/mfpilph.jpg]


In the last step is to screw the frontpanel onto the light-pipe holder, keeping it secure:

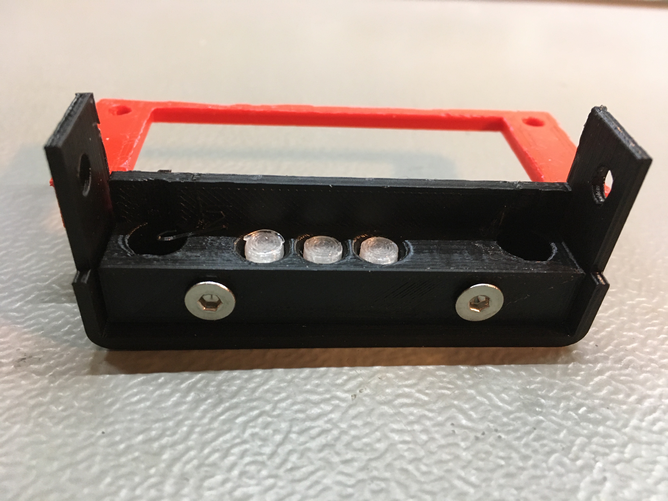
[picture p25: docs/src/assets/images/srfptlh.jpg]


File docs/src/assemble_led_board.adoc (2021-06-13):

== Assemble the LED Board
////
:imagesdir: assets/images
:includesdir: include
include::./{includesdir}/document_settings.adoc[]
////
The assembly of the LED Board is perhaps the most tricky one. Since space on the LED Board is quite limited, the footprint of the RGB LED's are somewhat "spaced close together". You get this when trying to solder the RGB LED's, without trying to bridge the pins together. 

To assemble the LED Board, the following is needed:

- 1x LED board
- 3x RGB LED
- 1x Solder helper tool (Trust me, you really want to 3D print this tool and actually use it)
- 1x complete cable with 2x (pre) crimped JST XH 10 pins 2.54 female connector
- 1x 10 pins JST XH connector

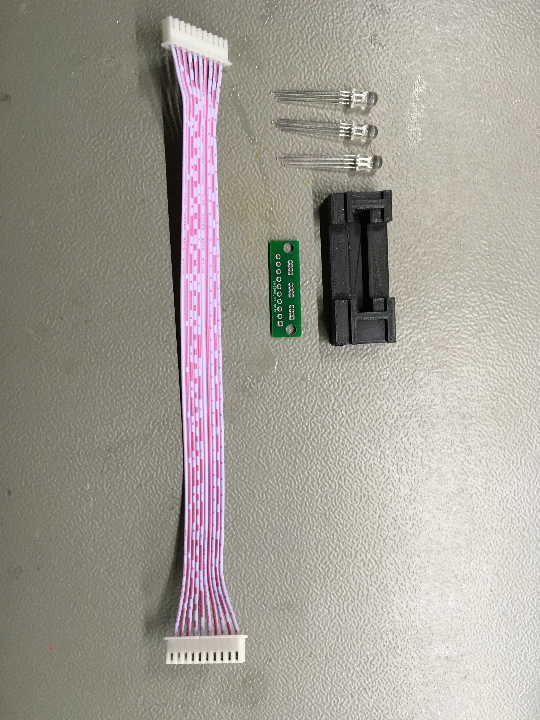
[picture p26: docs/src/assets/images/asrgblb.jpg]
Components needed for LED PCB assembly


=== Placing the RGB LED's
The first and most important thing is to insert the RGB LED's in the right orientation. The next image is demonstrating this:

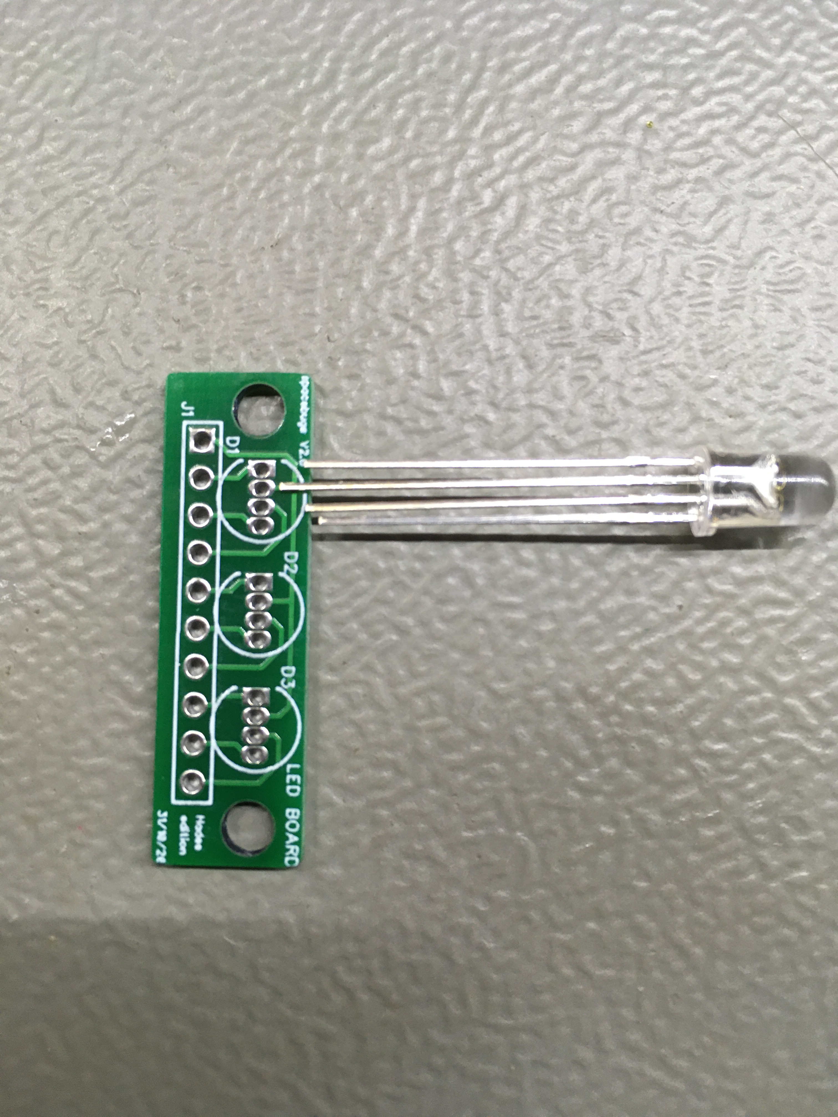
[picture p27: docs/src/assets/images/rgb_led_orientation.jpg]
RGB LEd orientation


Another way of looking at this is: On the PCB the LED markings have an open spot, the flat side of the RGB should be at this opening:

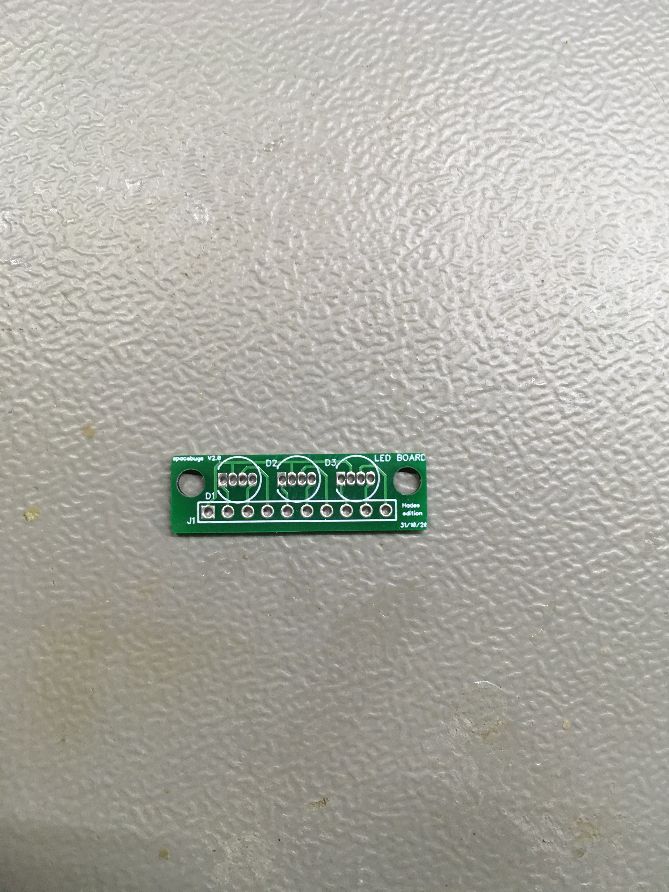
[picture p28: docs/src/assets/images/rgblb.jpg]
LED Board silk screen to orientate RGB LED's


After determine the right orientation of the RGB LED's insert them into the LED board:

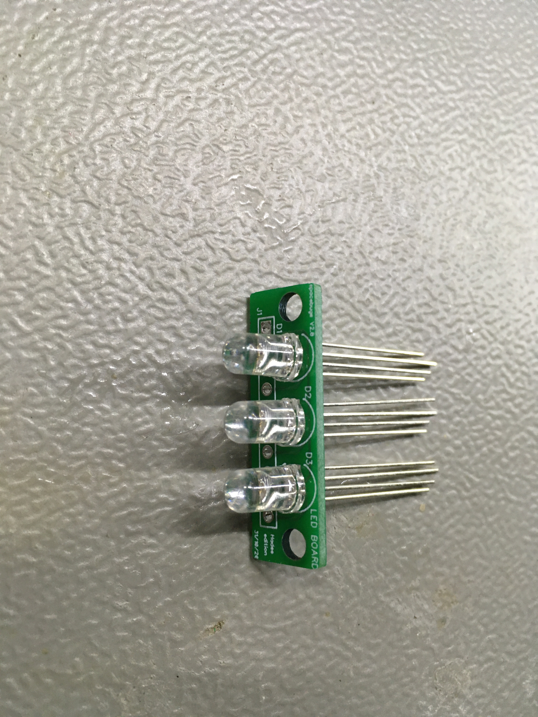
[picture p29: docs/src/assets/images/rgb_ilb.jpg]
Insert RGB LED's


=== Using the soldering helper tool

Add this point, you should have 3D printed the solder helper tool. Place the LED Board PCB as follows in the solder helper tool:

NOTE: To align the RGB flat with the PCB, there is only one way of inserting the PCB correctly into the solder helper tool

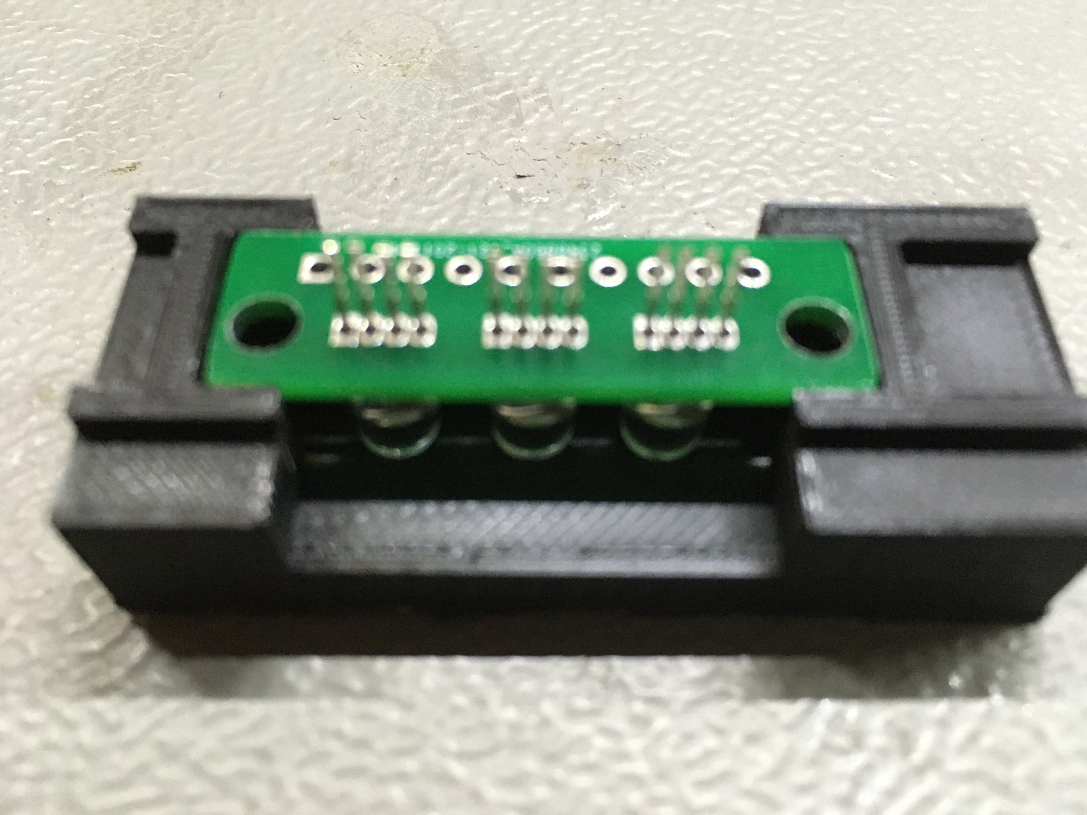
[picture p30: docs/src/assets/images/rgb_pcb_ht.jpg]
Solder helper tool


As you can see from the picture, it may help to cut the RGB LED's legs short, to make soldering even easier.

Once the PCB is inserted correctly, and the RGB LED's are flat with the PCB surface, solder all the legs of the RGB LED's without bridging them. 

TIP: To prevent bridging, use 0.5mm tin. And if pins are bridge, cut the legs short as possible and use solder wick to suck away the tin.

Solder the JST XH connector to the LED Board as follows:

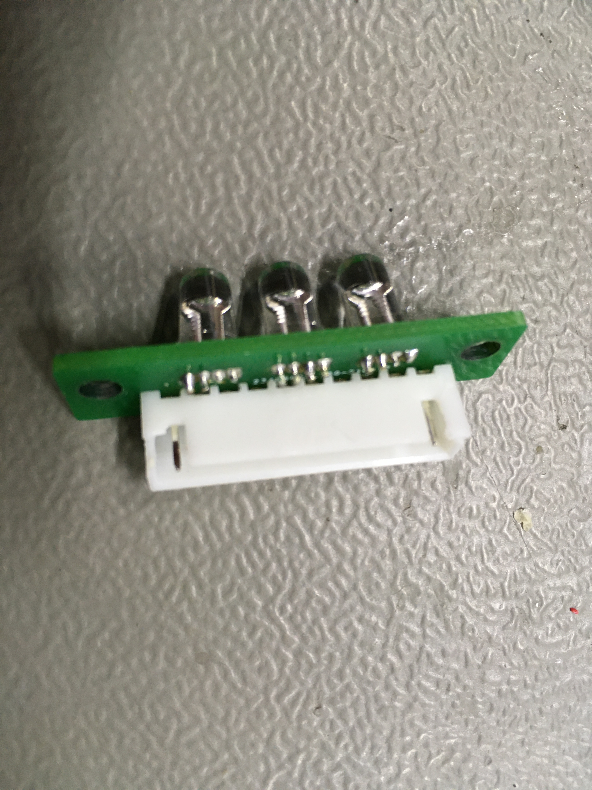
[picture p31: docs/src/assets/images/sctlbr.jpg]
Solder JST XH connector to the LED Board


Once the Connector is soldered, attach the cable: 

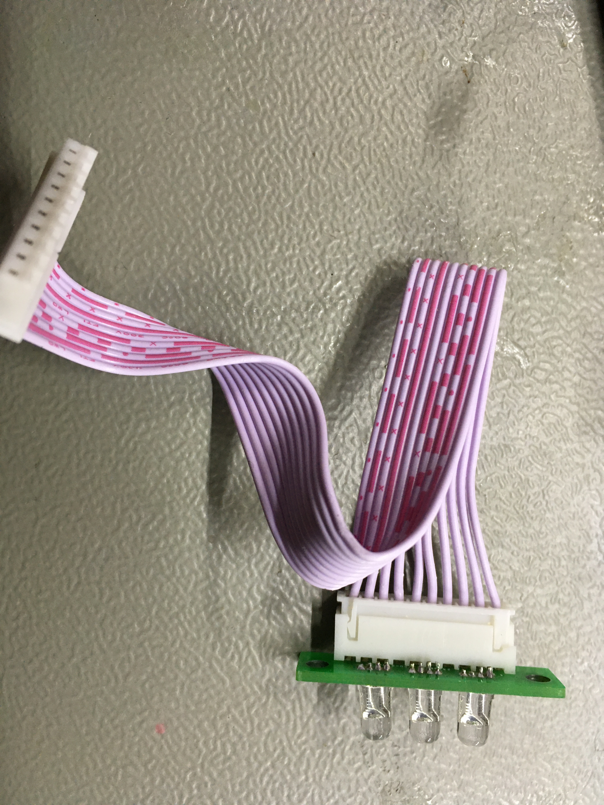
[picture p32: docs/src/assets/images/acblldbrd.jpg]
Attach the cable


=== Testing the LED Board

Once the RGB LED's and wires are soldered, the LED Board can be tested if you have a 5V power supply (for example a LAB Power supply)

On the LED Board the GND pin is marked. Stick a wire which is thick enough into the correct hole in the connector, which aligns with the GND pin. You can use a Multimeter and it's continuity tester to verify this. Connect the GND wire to a lab power supply. Next use a 330Ohm resistor, and use for example crocodile clip to hold the resistor. Connect the other end to the plus of the power supply and supply 5V with low Amperes ( around 20mA) 

Insert the resistor into the hole next to the GND and should see a color light up, move the resistor to the next hole, and another color should light up. Repeat this process for all the RGB LED's. If all the three RGB LED's are working, the assembly of the LED Board is completed.

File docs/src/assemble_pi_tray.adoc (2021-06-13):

////
:imagesdir: assets/images 
:includesdir: include
include::./{includesdir}/document_settings.adoc[]
////
== Assemble the PI Tray
Do you remember that a long, long time ago you prepared the PI Tray at the very beginning of this Hardware manual ? Well, now is the time to blow the dust of it, and start assembling the PI Tray. 

To assemble the PI Tray, the following is needed:

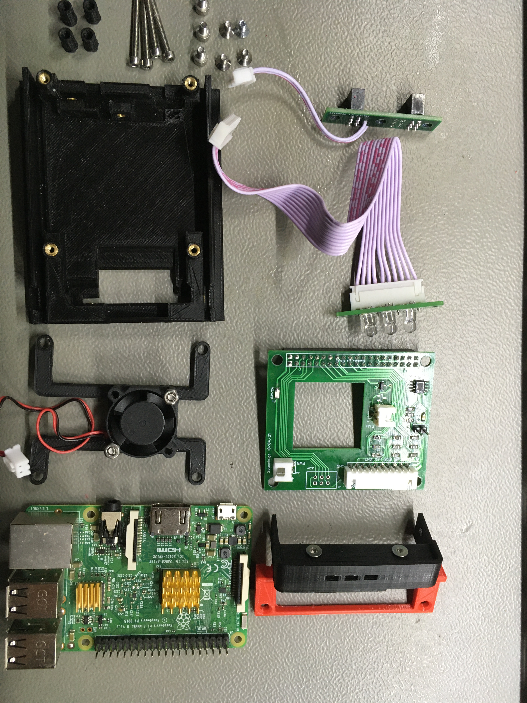
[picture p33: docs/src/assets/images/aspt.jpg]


- 1x Raspberry PI3 (or PI4)
- 1x An prepared PI Tray
- 1x An assembled PI Cluster HAT
- 1x An assembled Power Board
- 1x An assembled LED board
- 1x An assemble front panel + bezel
- 1x 3D printed fan holder
- 4x 3D printed stand-off
- 1x 5V Fan + wire + JST XH 2.54 connector
- 4x M2.5x25 bolt
- 5x M3x5 bolt
- 2x M2x6 bolt
- 2x M3x16 bolt
- 2x M3 nut

TIP: The 2x M3x5 bolt can be replaced with 2xM3x6 bolt. Another thing to consider is to use metal M2.5 stand-off with M2.5 bolt/screw. 

=== Place and attach the Power Board to the PI Tray
The first step is to attach the Power Board. The PowerBoard should click into place:

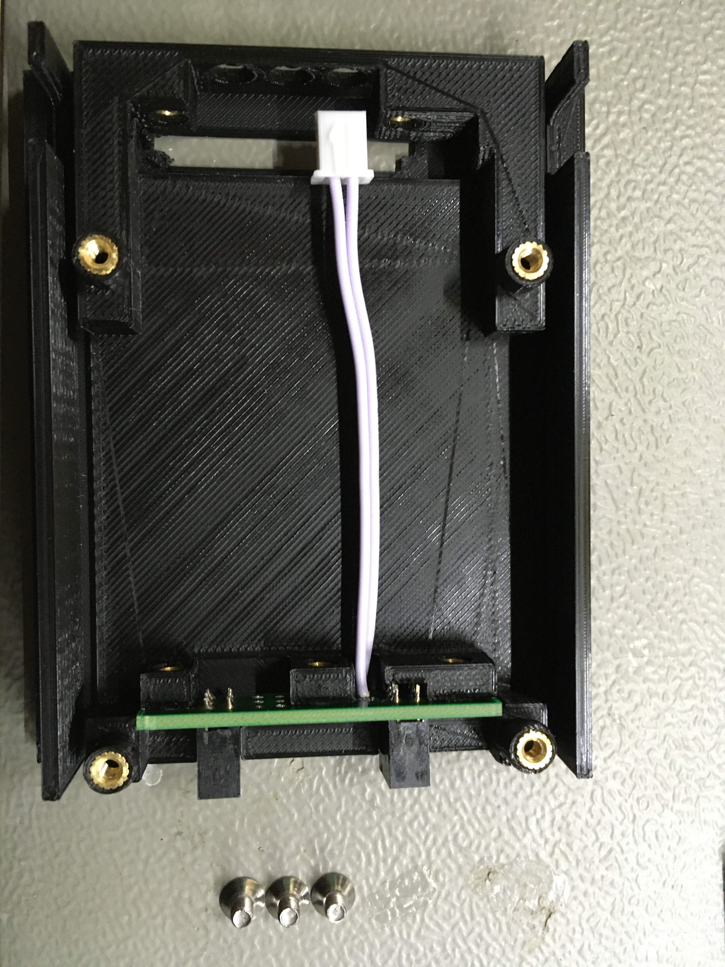
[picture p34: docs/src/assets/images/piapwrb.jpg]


When the board is correctly fitted, use 3x M3x5 bolt to screw the board into place.

=== Place and attach the LED Board to the PI Tray
Next the LED Board can be placed. The easiest way of placing the LED board, is to put it in under a angle, face the LED's down in a angle, towards the front of the PI Tray. The LED's should line up with the 3 holes in the front of the PI Tray. Next push the underside of the PCB into the cut-out. It should click into place. This may require some force, but don't use to much force. 

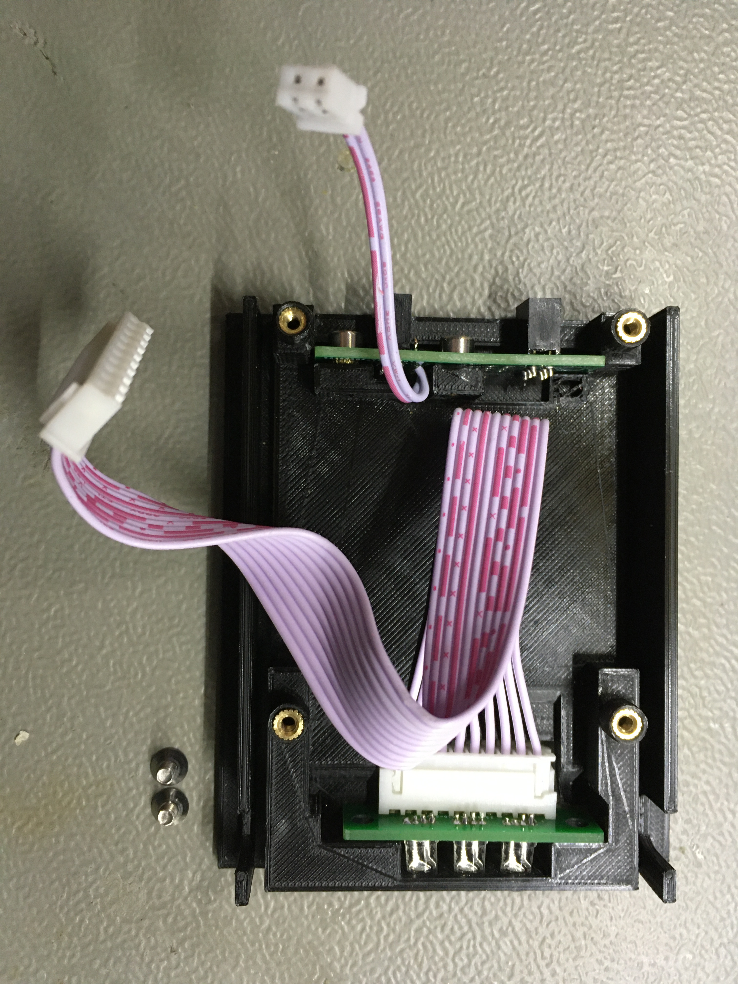
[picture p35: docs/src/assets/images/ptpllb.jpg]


Once the LED Board is correctly placed, use 2x M3x6 bolt to secure the board in place:

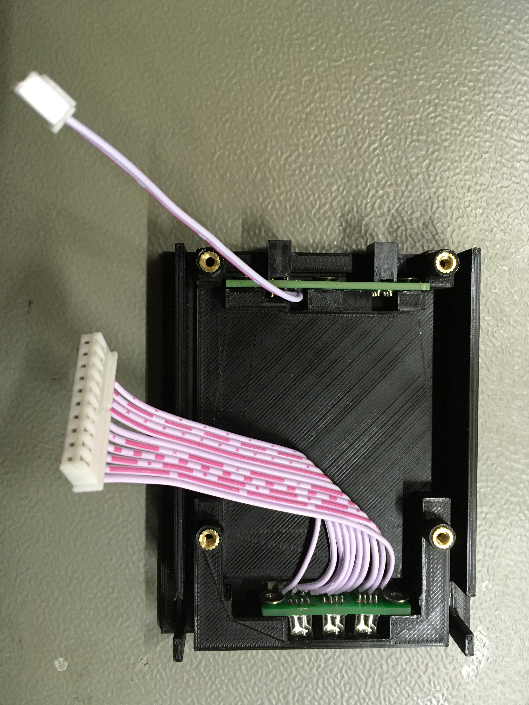
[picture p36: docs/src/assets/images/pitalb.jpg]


=== Attach the FAN to the FAN holder
The FAN should be placed correctly on to the FAN holder. This means the FAN should suck in cool air, and blow the air against the CPU. 

TIP: To determine in which way the FAN spins, connect the 5V FAN to a 5V PSU, and use a small piece of paper. Hold this small piece of paper close to the FAN, while it's spinning. If the piece of paper moves towards the FAN, the air is sucked in. If however the piece of paper is blown away from the FAN, the FAN is blowing air out. 

When connecting the FAN take note of the FAN holder. The FAN holder fits only in one direction:

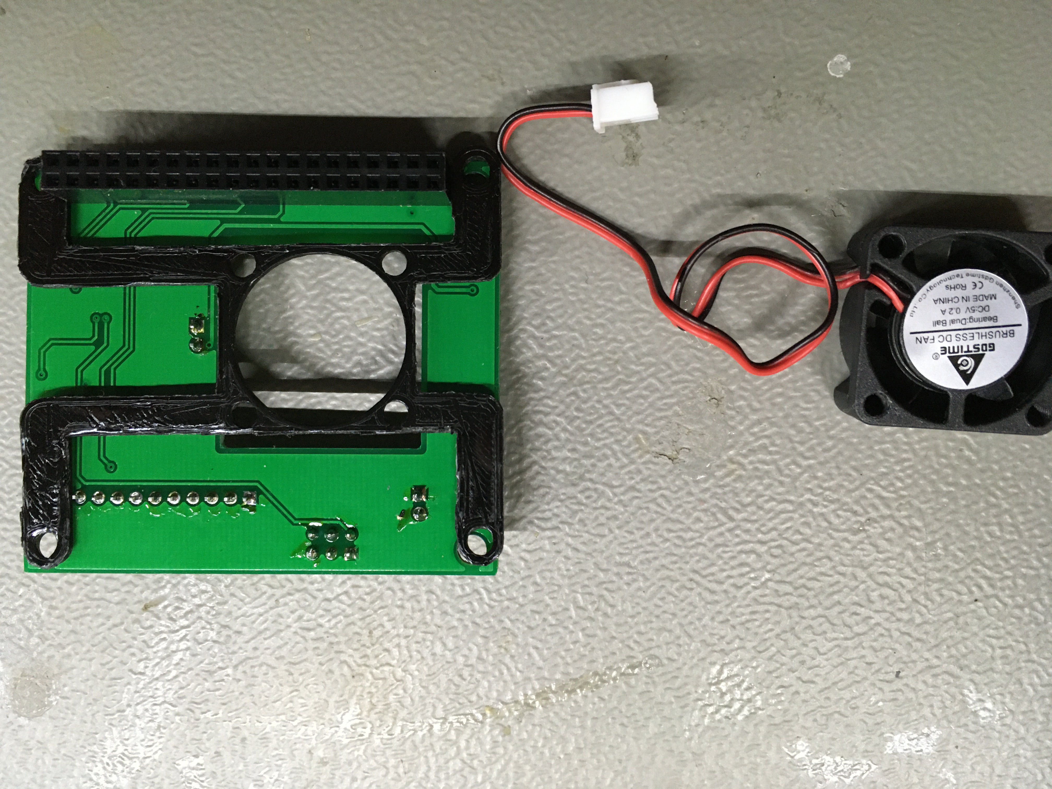
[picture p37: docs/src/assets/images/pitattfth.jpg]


When the correct position of the FAN holder is determined, screw the FAN onto the FAN holder:

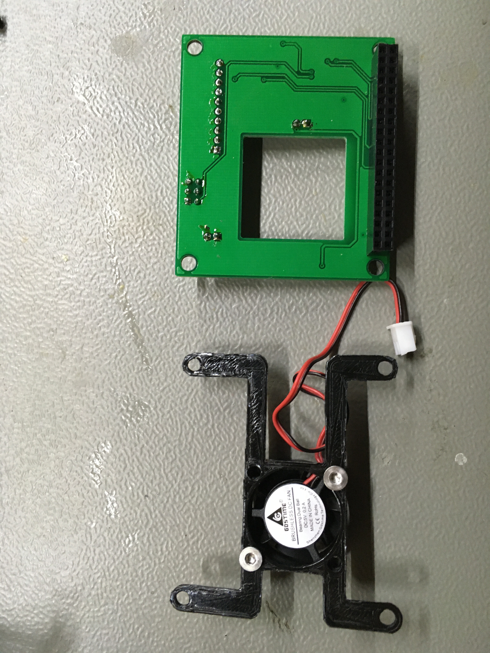
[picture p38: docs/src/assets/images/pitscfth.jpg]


Finally attach the FAN holder onto the PI Cluster Frame. Make sure that excessive wire is out of the way of the FAN

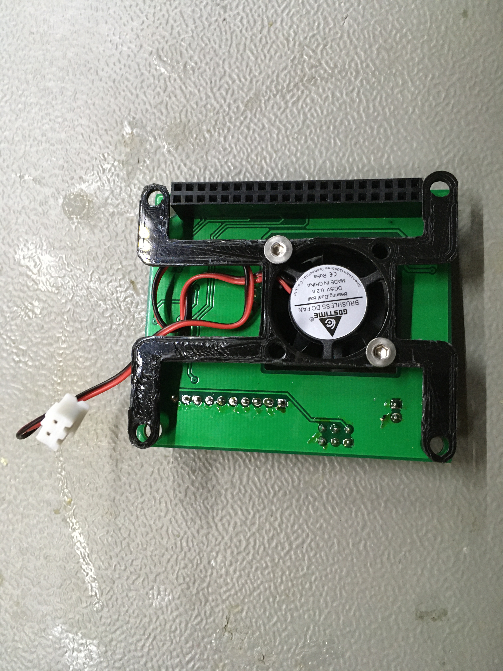
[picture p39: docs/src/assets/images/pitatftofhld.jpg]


=== Attach the Raspberry PI and PI HAT together
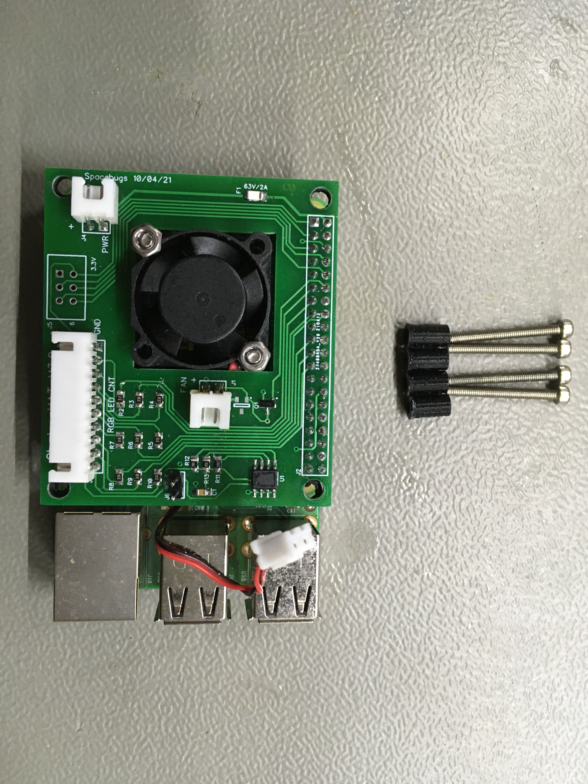
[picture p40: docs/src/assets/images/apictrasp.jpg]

To attach PI Cluster HAT onto the Raspberry PI, 4 3D printed stand-off can be used with 4x M2.5x25 bolt. However, you could also use metal stand-offs with the same height. Personally I prefer to use long screws with the 3D printed stand-offs. The funny thing is that I discovered this by accident. I didn't had enough M2.5 metal stand-offs in stock. So I quickly sketched some PLA stand-offs, and used at that time M3x25 bolts. And I discovered that by using this construction I can simply unbolt 4 bolts, and take the hole PI assembly of the PI Tray, which make swapping a PI or an other component a breeze. 

Anyway: Start by pressing the PI Cluster HAT somewhat down on the 2x20 male header on the Raspberry PI. Don't push the PI Cluster HAT all the way down. This makes inserting the 3D printed stand-offs easier:

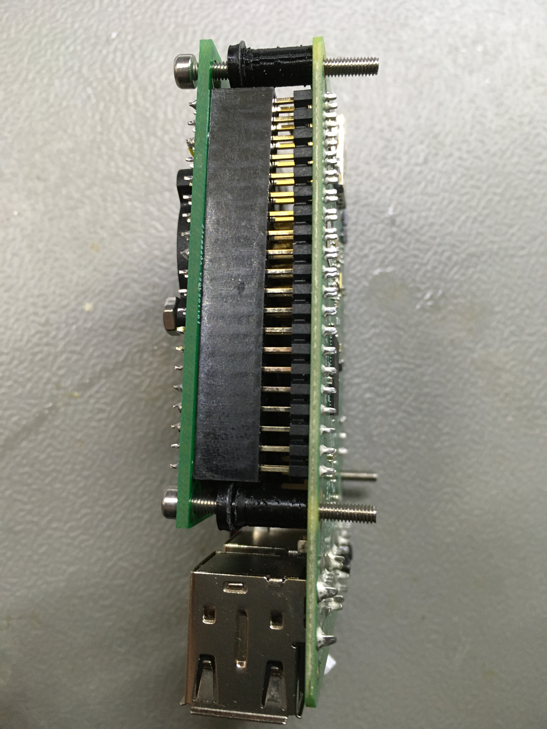
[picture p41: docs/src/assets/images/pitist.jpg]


Insert the 4x 3D printed stand-offs and 4x bolts.

If the cable connecting the RGB LED's is quite long, it can be folded like: 

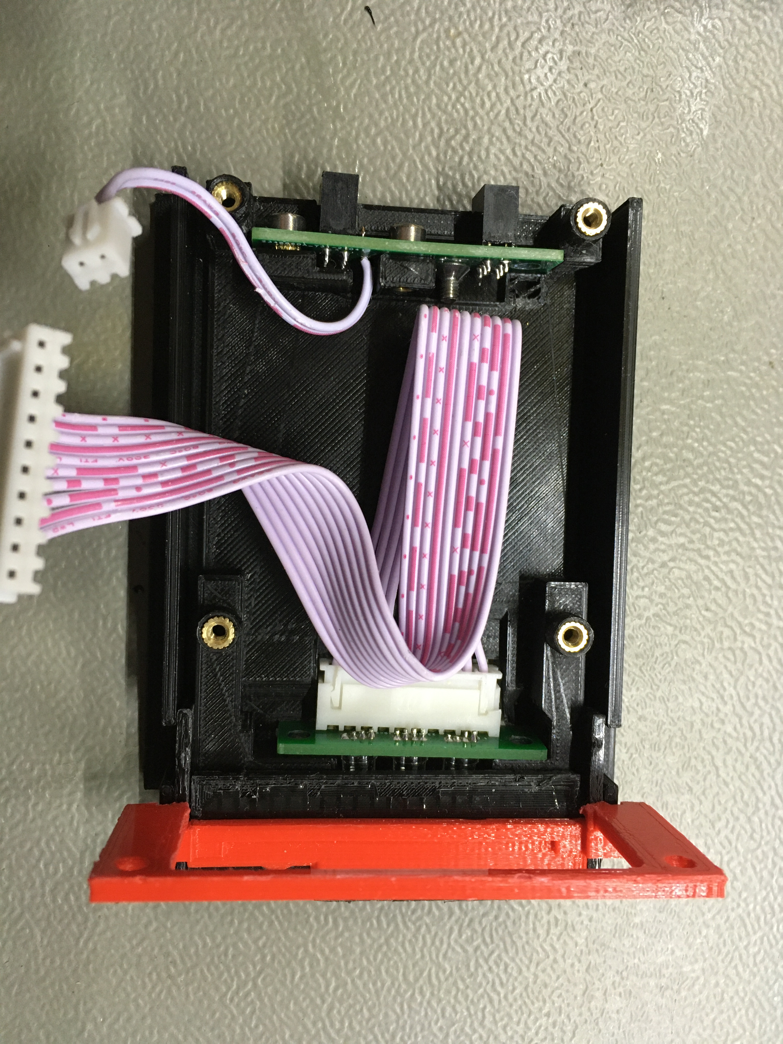
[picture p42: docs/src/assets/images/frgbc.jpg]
 

Note however when using a long cable, and using heat-sink on the bottom of the PI, the cable might not fit perfectly.

Place the whole assembly of the Raspberry PI and the Pi Cluster HAT onto the PI Tray, align the holes with the four bolts.  Press the PI CLuster HAT down onto the Raspberry PI (if you not had done this already) 

Screw the assembly into place. Make sure the power cable on the back is not between the Raspberry PI and the SD card holder, by making sure the power cable is guided along the corner:

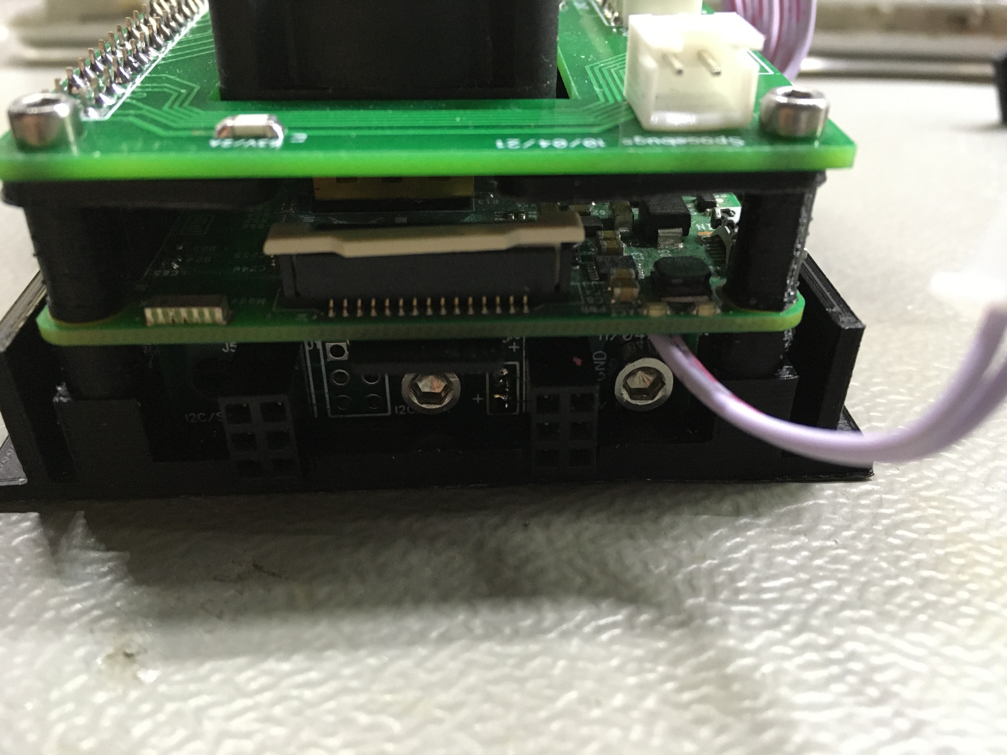
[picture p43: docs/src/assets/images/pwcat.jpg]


Connect all the wires: 

- Connect FAN wire
- Connect Power wire
- Connect the RG wire

=== Attach the front panel
The last step is to attach the front panel to the PI Tray using 2x M3x5 bolt:

Slide the front panel onto the PI tray:

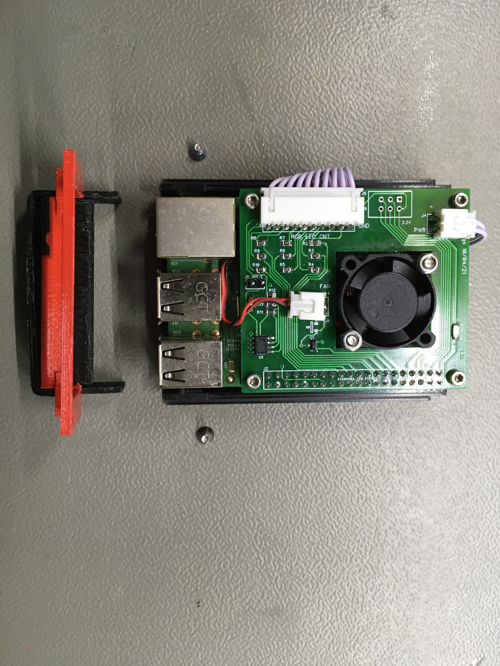
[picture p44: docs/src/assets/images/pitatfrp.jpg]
Place front panel


Secure the front panel into place with two screws, one at each side:

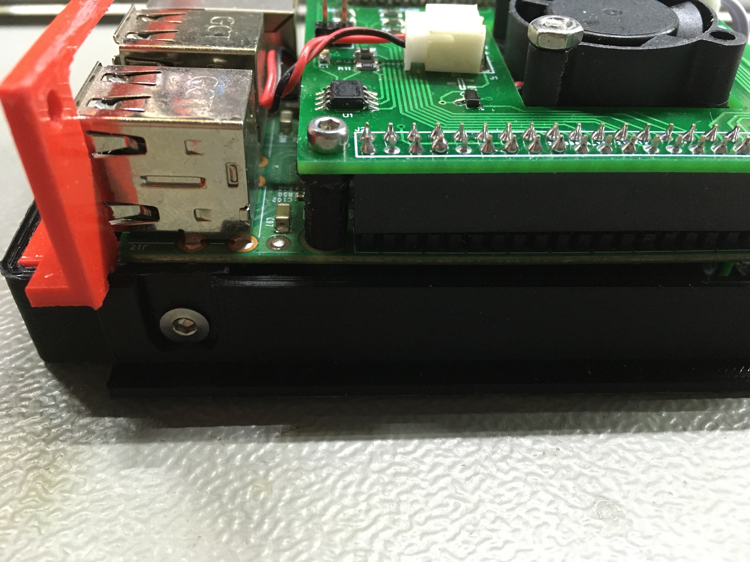
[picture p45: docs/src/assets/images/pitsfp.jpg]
secure front panel{fullWidth}


The finished PI Tray should look like this:

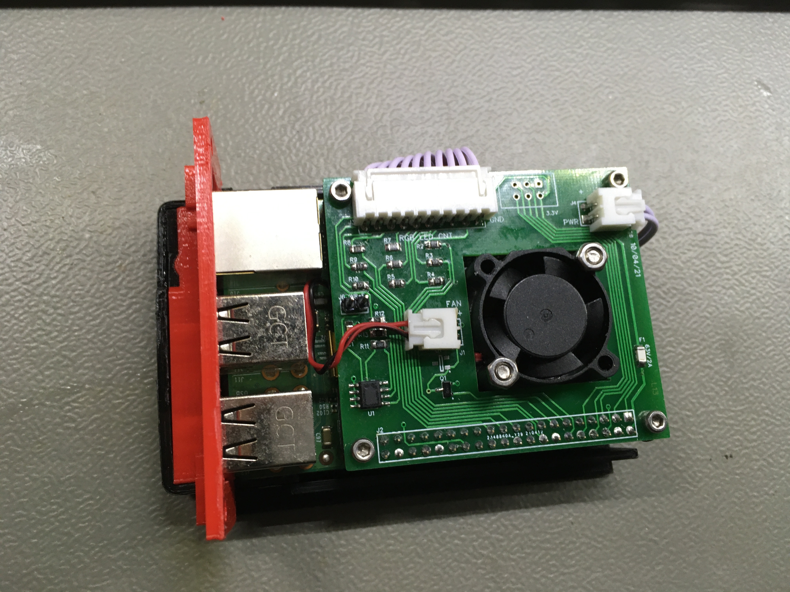
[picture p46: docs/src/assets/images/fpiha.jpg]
Finished PI tray


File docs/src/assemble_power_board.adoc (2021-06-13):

== Assemble the PowerBoard
////
:imagesdir: assets/images
:includesdir: include
include::./{includesdir}/document_settings.adoc[]
////
Materials needed:

- 1x Power Board PCB
- 2x 2x3 female 2.54 pitch connectors
- 1x JST XH 254 connector
- 1x JST pre-crimped connectors
- 1x 3D printed Connector alignment tool

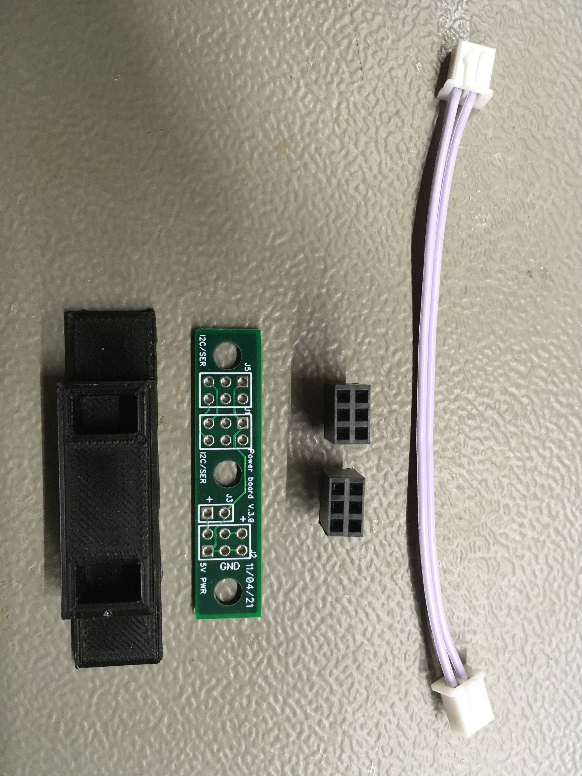
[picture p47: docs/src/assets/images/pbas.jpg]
Components needed for PowerBoard PCB assembly


NOTE: The JST XT 2.54 connectors can be bought pre-crimped. However the copper pairs, or most likely to be very thin, causing a severe power drop.

TIP: Before assembly make sure to print the alignment tool from the extra folder. This tools helps aligning the connectors, and makes soldering more easily.

Start by inserting the 2x 2x3 2.54 female headers in the alignment tool like this:

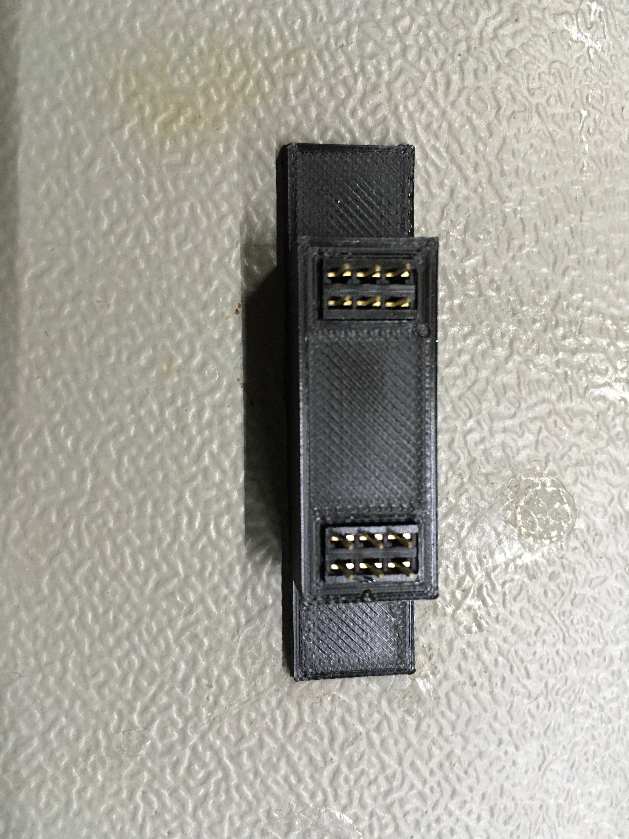
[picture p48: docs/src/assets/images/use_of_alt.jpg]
Using the PowerBoard helper tool


Next place the Power Board PCB with the silkscreen facing down. Make sure to align the PCB and the connectors with the most outer holes, so the PCB should be roughly in the center of the alignment tool. Press the PCB down, so it sits flat with the surface of the alignment tool:

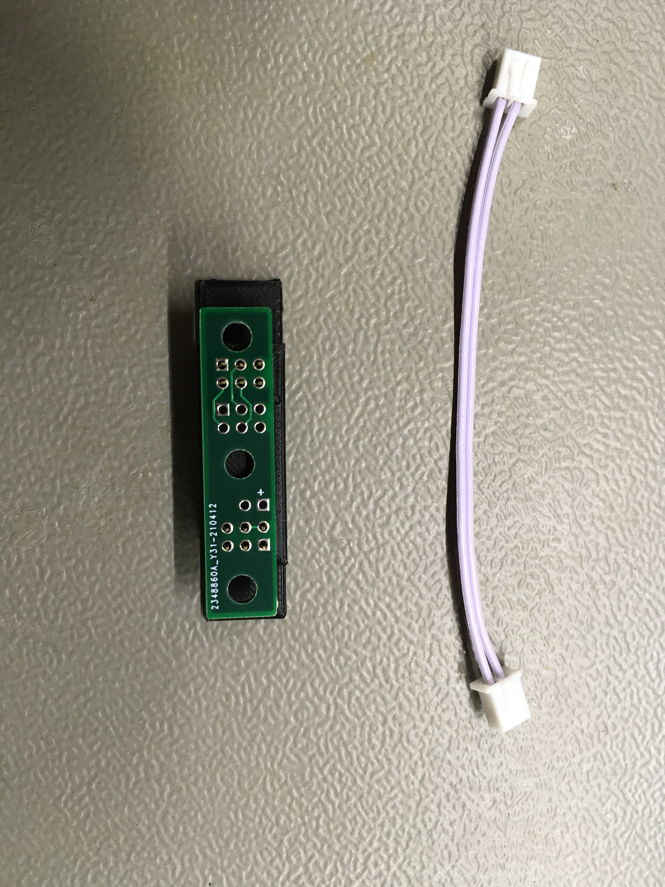
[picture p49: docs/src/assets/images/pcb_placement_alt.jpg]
Align PCB


Solder the connectors onto the PCB, and once the connectors are soldered remove the PCB gently from the alignment tool.

Next, cut the pre-crimped JST cable, using a 6.5CM length, and make sure that the guiding profile of the connector is facing upwards:

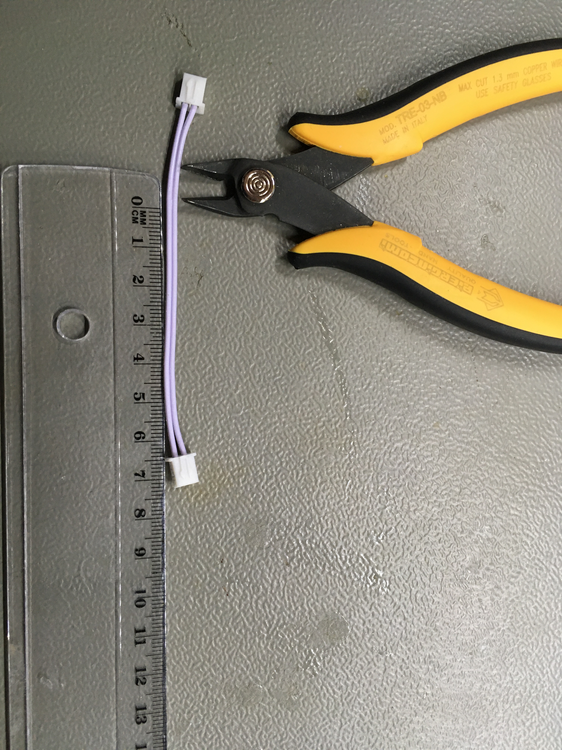
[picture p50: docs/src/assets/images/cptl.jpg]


The last step is to solder the wire onto the PCB. Make sure to solder the wire on the back of the PCB, and also make sure to get the polarity right: solder the RED (+) onto the plus (+) on the PCB:

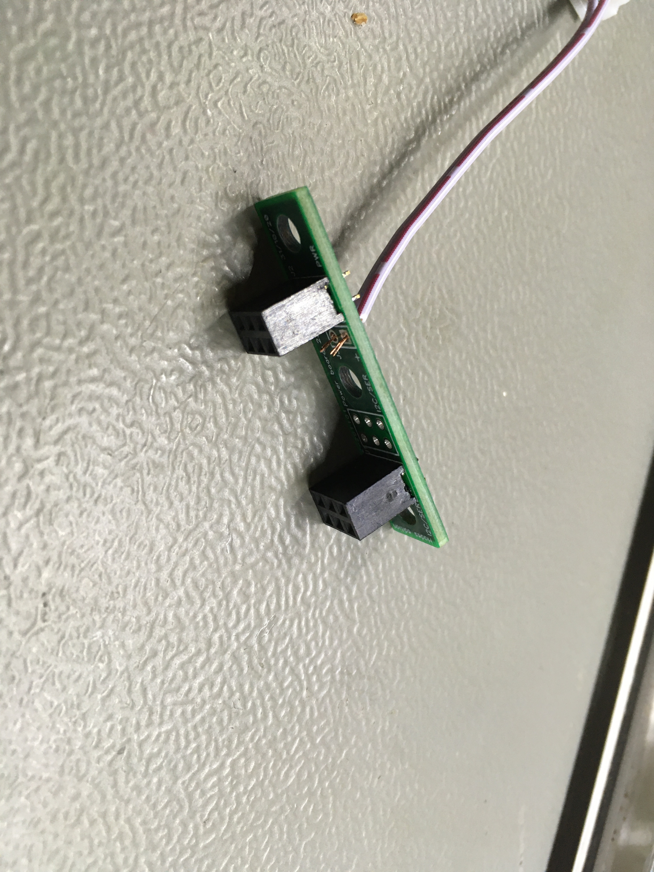
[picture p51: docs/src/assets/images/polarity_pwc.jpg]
Solder wire onto the PowerBoard PCB


The finished Power Board should look like this:

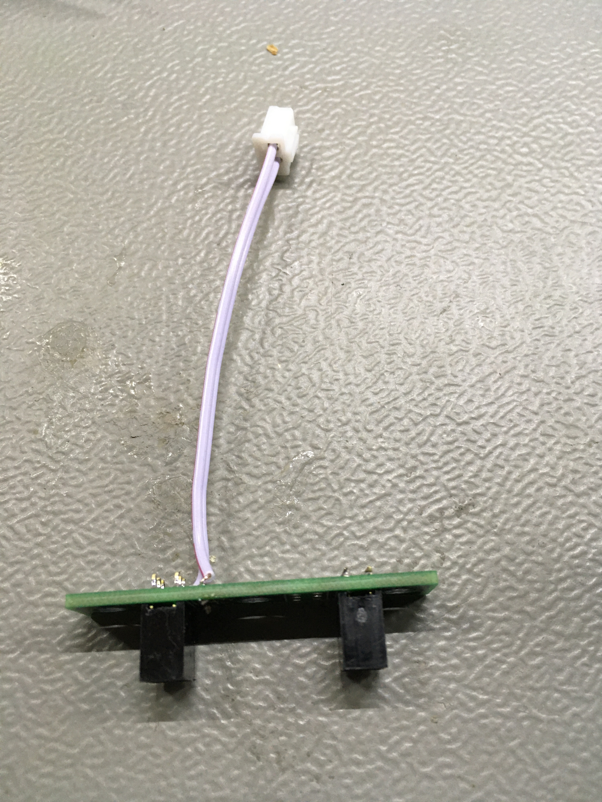
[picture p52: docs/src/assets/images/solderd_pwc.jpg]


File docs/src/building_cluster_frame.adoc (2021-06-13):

== Building the frame
////
:imagesdir: assets/images 
:includesdir: include
include::./{includesdir}/document_settings.adoc[]
////
To build 1 cluster frame, the following is needed:

- 1x backplate
- 2x front-plate
- 2x connecting rod left (or with two nodes 2x M3 press insert and 2x M3x50)
- 2x connecting rod right (or with two nodes 2x M3 press insert and 2x M3x50)
- 1x back-plane PCB
- 8x Brass press insert M3
- 4x M3x10
- 4x M3x25

=== Prepare the frame and place all the press inserts
The first step is to 3D print all the parts. When building a frame for 10 nodes this is a process that can take several days to complete. It's also possible to print the parts for 2 nodes (so one frame at the time). And extend the frame in the course of a few days. 

The 3D printed parts needed to assemble one complete frame are shown in the picture below:

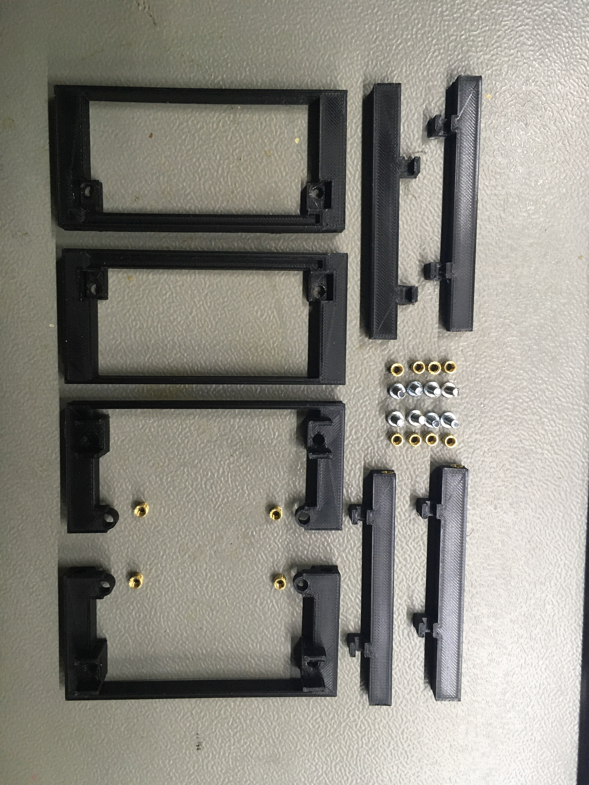
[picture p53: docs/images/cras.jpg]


Before starting the assembly, make sure to deburr all the edges. Next place the brass press inserts into both sides of the connecting rods using a hot conical tip from a soldering iron and gently press the inserts into the hole: 

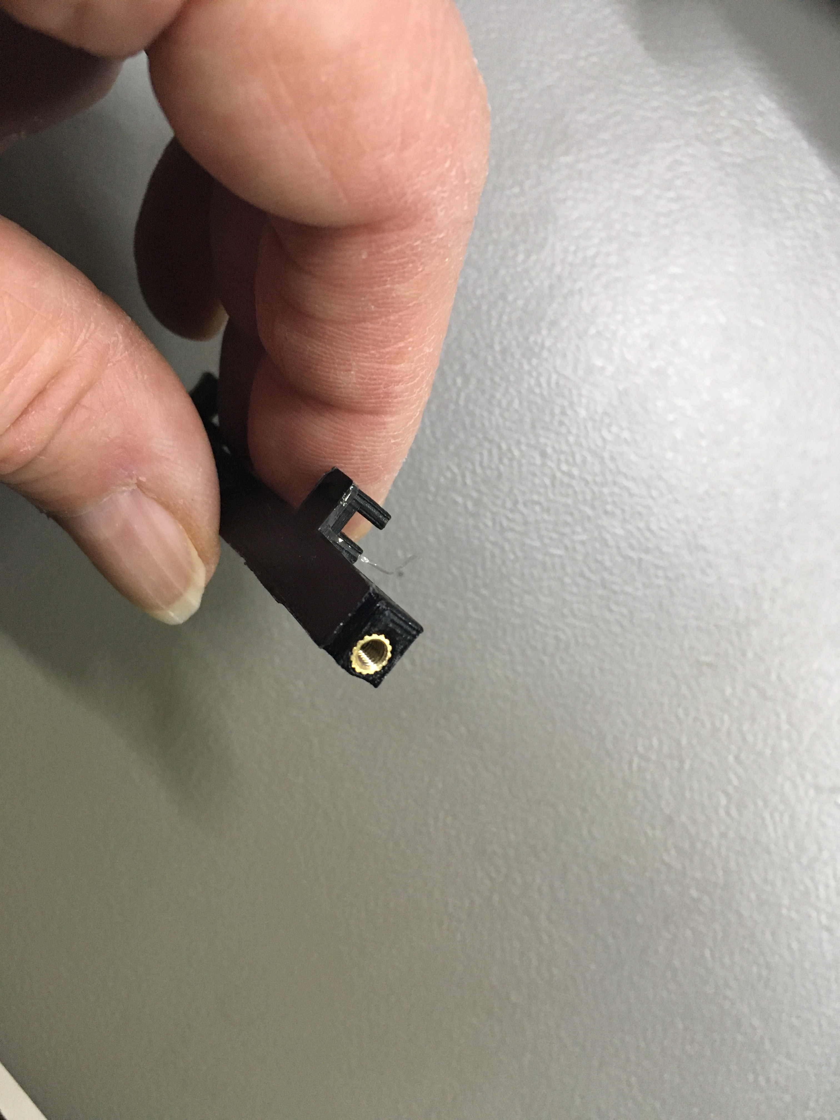
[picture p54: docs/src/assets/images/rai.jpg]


Make sure that the insert is level with the surface. So that the insert isn't sticking out, and make sure don't press the insert to deep.  Also make sure that the press insert is inserted straight. Inserting the press insert on a slightly angle will cause the frame to be out of alignment.  Once all the sides are done (four in total) the next step is to press the two remaining inserts into the top holes of the front plate: 

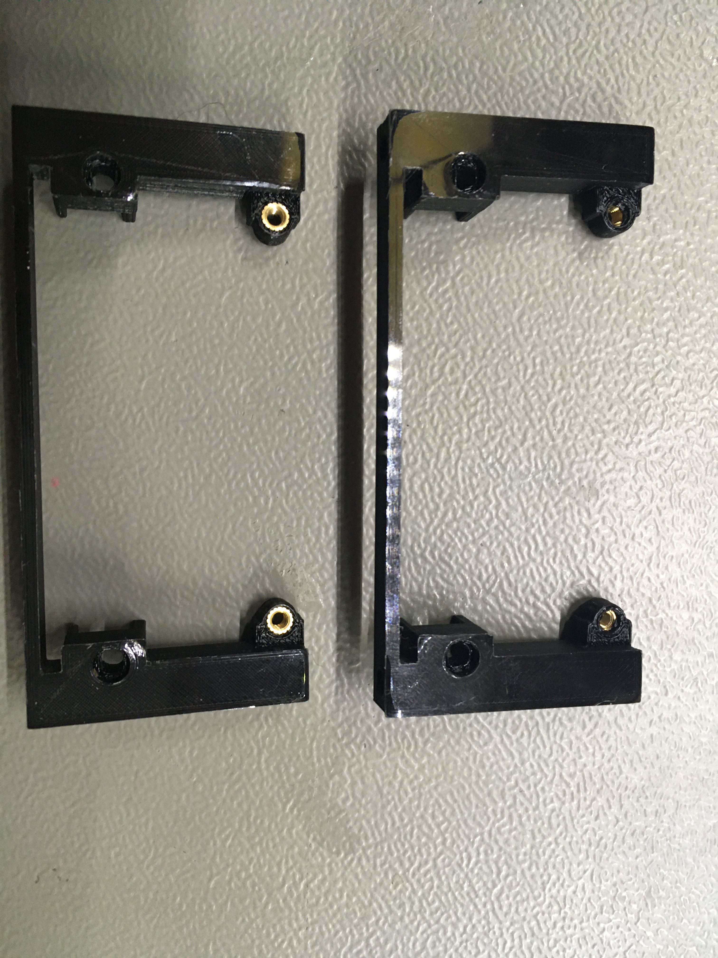
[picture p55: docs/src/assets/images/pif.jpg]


=== Put the frame together
Once all the press inserts are placed, the frame can be put together. This can be a bit tricky. The tricky part is to get the orientation of the connecting rods right. If the connection rods are examined closely there are two things to be noticed: 

. One connecting rod is somewhat smaller then the other
. At one end the corner has a little gap in it.  

This is done to make identifying the connecting rods somewhat easier. The next image shows the gap at the end of the rod.

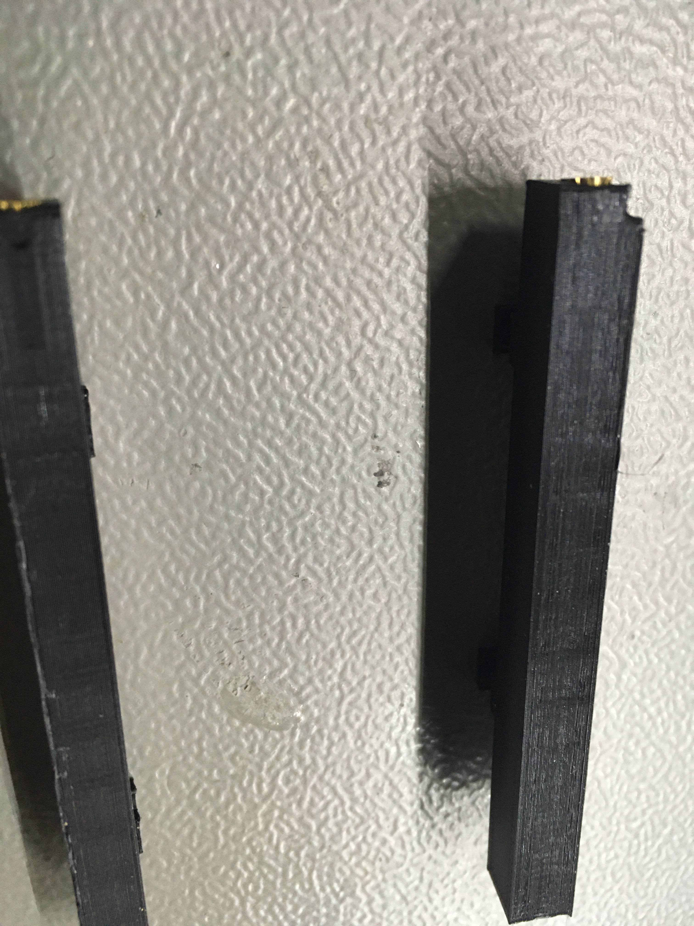
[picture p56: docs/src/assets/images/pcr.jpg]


This gap is there to allow a M3 metal rod connect all the clusters frame together. So this is the "back end". Place the front plate. Note the smaller rod (seen from the front) goes left, and the slightly thicker rod goes on the right. Make sure the guiders are facing inward, and downwards:. The gap at each end of the rod should face outwards:  

Buildimage

Use 2x M3x25 to screw the front plate in place. 

Next place the backplate. The screws used for now are temporarily, for now it's just to hold the frame together. The frame should now look like as shown on the next image: 

Buildimage

Now repeat the above steps to complete the second half of the PI Cluster frame. 

=== Testing the PI Cluster frame
Once both frames are build, completing one PI Cluster frame, the frame can be tested. This test is done to make sure a PI tray can slide in and out of both of frames. If the PI tray's don't slide easy look for burrs and deburr the edges were needed. 

First test by sliding a fully assembled PI tray back and forth, there should be little to none friction. If the PI tray must be forced, something is not right. 

Buildimage

Also test if the PI tray can be inserted fully. The front plate should be flat, and nothing should stick out of the front: 

Buildimage

Once all the test are completed, and everything is working fine, the back-plane can be attached.

=== Attaching the back-plane
Attaching the back-plane can be tricky and somewhat fiddly. The back plane purpose is the distribute power and other signals. The connectors on the back-plane must therefore mate perfectly with the connectors on the PI tray. This alignment can be tricky. Luckily there are some tricks to get it right. The mounting holes in the back-plane for example are slightly larger, so there is some wiggle room. 

The next method is exploiting this 'extra wiggle room'

The align the connectors you need:  

- 2x fully assembled PI tray
- 4x male 2x3 2.54 (.001 inch) pitch connector

The first step is to insert the 2x3 male connectors into the female 2x3 connecters on the back of the PI tray: 

Buildimage

As can be seen on the picture above make sure that the long pins goes into the connectors on the PI tray, and that the short pins are sticking out.

Next place the back-plane onto the cluster frame. Make sure to unscrew the four temporarily screws on the back. You need this four screws to hold the back-plane temporarily into place. 

Position the back-plane as shown in the picture: 

Buildimage

place the back-plane onto the frame and screw it into place. However, don't tighten the screws too tight. The back-plane should be easy to move around, with being to loose. 

It should look like this: 

Buildimage

Now place on of the PI tray's into one of the frames, and gently push it against the backplane, if needed gently move the back-plane around, and wiggle the PI tray till the connectors align with the back-plane. You should see the connector pins sticking out of the backplane: 

Buildimage

While keeping the PI tray into place, secure the PI tray with 2x M3x10 in place. And repeat the step above for the other PI tray. 

Once the connectors are aligned for both of the PI trays, tighten the screws of the back-plane, so that the back-plane is held in to place. The last step is to solder the pins onto the backplane. Once the pins are soldered, the PI trays could be loosened by unscrewing the two front screws. The PI trays should not slide out of the frame, and by reinserting the PI frame, the connectors should align with the back-plate connectors without any problems. 

=== Attach the frames together
Once the backplane is placed, and the PI nodes are fitting perfectly, and can be slide in and out , the frame can be screwed together. This is done by using M3 Rod which needs to be cut to length. This can be done by using a dremel tool for example. Measure the length of of the rod to cut, and cut four equal sizes. Push the rod trough the holes in one of the corners of the frame. Once the rod is pushed all the way trough, place a M3 nut on both side, and tighten up the nuts, but not to tight. Replace this process for the rest of the three corners. 

When using only two nodes, it's possible to use 4 press M3 inserts and 4x M3x50. Note however that expanding the frame is no longer possible. To connect the frames with screws: 

place the press inserts

screw the frames together: 

srew fram together

If however the frame must be extensible, it's better to measure the needed length of four M3 rods, and use 4x M3 nuts to bolt the frame together.

=== Power supply considerations
Before connecting the backplane, and bringing the PI cluster up and running, there is the small matter of getting a power supply. The most likely this will be a Switch Mode Power Supply (SMPS). The things to consider for buying a SMPS are the following: 

. Make sure the SMPS outputs 5V and ideal is adjustable to for example 5.1V
. MAke sure the SMPS can handle the load. That is: The SMPS must be able to deliver the Amperes. Buy a SMPS which can deliver a few Amp more then required.
. Don't buy the cheapest SMPS you can get. Make sure the SMPS is safe to use, and is of good quality. 
. Check the power consumption of the PI model(s) which are going to be used in the PI Cluster Frame

When building a one frame cluster (thus two PI nodes) the SMSPS doesn't have to be very beefy. However if you want to expand the PI Cluster Frame from two PI's to let's 4 or of 8 or even 10 PI's it might be better to buy a PSU which can support this expansion. To give an idea, for a 10 node cluster with PI3's I use a 5V 26A SMPS (Mean Well RS-150-5) .

See the the section below on the Amperes and requirements.

=== Connecting the backplane
The backplane connects to a 5V power supply, and distributes the power to all the nodes in the cluster. When using more then one frame (thus more then two PI tray's) the backplane must be connected together. This can be done in two ways: 

- Connect the backplanes in series
- Connect the backplanes in parallel

The image below shows how the backplanes can be connected:  

Buildimage

The "secondary connection" can be made to decrease the possible voltage drop due to the wiring.

When connecting the back-planes, the goal is to minimize the voltage drop. This voltage drop is caused by the wiring, and the back-plane itself, and the connections to the PI tray's (thus the PI nodes). The Raspberry PI operates at 5V, and doesn't cope very well with voltages below 5V. For example 4.9V might not be a problem, but 4.63V (+/- 5%) will definitely give problems. 

The rule of the thumb is: The thicker the wire, the less voltage drop. Think of Ohm's law: if every piece of copper and connection is considered as a resistor, a voltage drop occurs across the resistor. By dropping the resistance, less voltage drop. Another thing which comes into play is the amount of current. For higher amount of current, thicker wire is needed. If the wire is to thin, it would get very hot, and can even burst into flames. And you might think.. well these are little Raspberry PI's.. so that's not a issue. For two Raspberry PI's it might not, but if you connect 10 of them.. it becomes a issue. To keep it simple: let's say one PI node consumes 1 Ampere , now if we multiply that with 10 nodes.. it's 10 Ampere.. And now think about what a Raspberry PI3 or PI4 is able to consume. Let's say 2 Ampere.. that would mean 10x2 = 20 Ampere.. Luckily we can reduce these numbers. 

By connecting the backplane in series, the idea is that each backplane (which holds two PI's) can only consume at max 2x3A = 6A (For a Raspberry PI 4 Model B). However, for a Raspberry PI Model 3(A+B), and model 4B the maximum total USB peripheral current draw is 1.2A. This reduces the previous calculation to 2x.1.2A = 2.4A. Looking at a average consumption it's about 500mA for a Raspberry PI3 B+, and for a PI4 B it's about 600mA. So if we calculate on 600mA for two Pi's it's: 2x 0.6 = 1,2A. 

The numbers above are taken from: https://www.raspberrypi.org/documentation/hardware/raspberrypi/power/README.md 

The moral of the story is: 

- Don't underestimate the current needed.
- When connecting the backplanes, and depending on the amount of nodes in the cluster make sure to have a Power Supply (PSU) which can deliver enough Amperes
- Connect the backplanes in series. This might be more challenging to connect all the wires to one central connector. However this decreases the voltage drop
- Use a XT60 as a central connector to supply the main 5V. These connectors are able to handle the amount of current.

When connecting the backplanes in series (not recommended):  

- make sure to use thick wires.
- If possible connect the backplanes with two wires, the decrease the voltage drop.

The connections of the back-plane connect to one XT60 connector which is mounted on a back-plane cover. See the section <<Attaching the backplane cover>>

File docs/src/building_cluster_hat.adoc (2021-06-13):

== Building the PI Cluster HAT
////
:imagesdir: assets/images 
:includesdir: include
include::./{includesdir}/document_settings.adoc[]
////
The PI Cluster HAT PCB contains SMD parts and also Through Hole parts. It may require some skills to solder these SMD parts, but it shouldn't be too hard to do, since the SMD package size is rather large (SOT-23-3 and 0805). 

Per PCB you need: 

- 9x SDM 0805 330 Ohm resistor
- 2x SMD 0805 3.9K Ohm resistor
- 1x SMD 0805 1K Ohm resistor
- 1x 2 Amp SMD 1206 fuse 63V 2A Slow blow
- 1x CAT 24c32 EEProm
- 1x NDS351N MOSFET (SMD sot-23-3) 
- 2x 10 pins JST XH cable connectors (these are available already crimped to a cable)

Depending on how you connect everything to the PI Cluster HAT:

- Solder the wires directly onto the PCB
- Use connectors

When using connectors you need the following:

- 1x 40 pins GPIO header
- 1x  10 pins JST XH 90 degree angle PCB connector
- 2x 2 pins JST XH 90 degree angle PCB connector
- 1x 6 pins box header

The pro of soldering the wires directly to the PCB is the low profile. The downside is of course that when removing or when needing to replace a part, the wires needs to be de-soldered. 

When using connectors, all the connections can easily be disconnected. Which makes maintenance much easier. However, it costs more.

Whichever solution you choose, it doesn't matter, as long as the profile of the PCB is as low as possible.

=== Soldering the PCB
When starting to solder the PCB, first start with the SMD components:

Components needed for PCB assembly{fullWidth}

Next solder the JST XH 2.54 haeders onto the PCB

Components needed for PCB assembly

As a last step solder the 6 pins 2.54mm header if needed (currently not used), and then the as the last component the 2x20 GPIO pin header at the other side of the PCB. The final PCB is shown below. In a last step the FLUX must be cleaned up from the PCB. But apart from that, this is how the finished PCB should look like.

Components needed for PCB assembly

NOTE: During development, the PCB version 2.0 (Hades Edition) a few bodge wires where needed, to let the MOSFET do it's work. Also note that the test points are shorted together, allowing the EEPROM te be written. 

When soldering the PCB start with the smallest componets. So first solder the resistors, the and the other SMD components. Next solder the connectors (if you choose to use connectors). Solder the 2x20 GPIO header as last part. Make sure the GPIO header is straight, and in a 90 degree angle to the board.

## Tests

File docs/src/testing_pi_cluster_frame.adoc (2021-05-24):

== Testing the PI Cluster Frame
Once the backplane are connected, perform the following test before applying power: 

- Remove all PI trays (PI nodes) from the chassis 
- With a Multimeter in continuity mode check for shorts on the back-plane. For example: start by testing between the pins of the XT60 connector
- Check each back-plane for shorts. 
- Next when no shorts are detected (or all are fixed) without any PI node in the cluster chassis, apply 5V to the cluster chassis
- Measure the voltage on each backplane 5V connector

When everything looks okey: 

- Use a lab power supply (if possible and limit the current to 600mA)
- Insert one PI tray into the chassis. 
- Apply power and see if the PI node starts without problems. 
- Measure the voltage on the other pins on the back-plane

Once everything is okey insert the second PI node, let it boot. And after each successfully power up of a node, insert the next PI node until the whole chassis is populated and all nodes are booted.

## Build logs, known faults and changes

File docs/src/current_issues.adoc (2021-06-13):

////
:imagesdir: assets/images 
:includesdir: include
include::./{includesdir}/document_settings.adoc[]
////

== Current issues
The current PI Cluster version is still in the development phase. This means there are some issues. So before building the PI Cluster Frame, you may take a look at the current known issues. However the cluster frame itself is fully working. 

NOTE: Currently the PI Cluster frame (version: {current_version}) is at a point that it is useful. There are however some issues that needs to be addressed:

. The back-plane connectors doesn't align properly with the Raspberry PI
. The documentation is not fully completed yet or contains errors. 
. When using a PI4 it's difficult to remove the Ethernet cable.
. The rack-mount ears or not fully developed and tested.

:sectnums:

=== Back-plane alignment issue
In the development version *{development_version_beta}* the back-plane connectors don't align well with the PI Tray's connectors. Currently the Power connectors work. However the connectors which can be used for I2C are not tested, or operational. This misalignment makes placing the back-plane onto one PI Cluster Frame quite difficult, however it can be done. Once the back-plane is correctly aligned, both connectors should mate perfectly with the connectors on the PI Tray. However this is not tested with multiple PI Cluster frames stacked together. 

Severity: *HIGH* : Currently it is not advised to manufacture the PI Cluster back-plane PCB's until this issue is fixed or completely tested. 

*SOLVED* Issue is resolved in the current version *{current_version}* The alignment of the connectors is not perfect yet, but with the procedure explained in the  <<Attaching the back-plane>> section the alignment shouldn't be a problem. 

=== . The documentation is not fully completed yet or contains errors.
The documentation is becoming more and more complete, however it still needs a lot of work. At this point most of the assembly instructions should be complete. However the document itself is not tested fully, and may contain errors.

Severity: *HIGH* Documentation is required to be able to build the PI Cluster Frame. 

In the {current_version} all of the assembly steps are documented, however the documentation can (and properly will) contains errors, since it's not tested fully.

=== When using a PI4 it's difficult to remove the Ethernet cable
When a Pi4 is used in a Pi Tray the Ethernet port is on the right side instead of the left side. On the left side there is a small cut-out, so it's easier to remove a ethernet cable. However this cut-out is not available on the right side. Making it difficult to detach a ethernet cable.

Severity: *LOW*  This is just an inconvenience, and the front bezel needs a redesign anyway. 

=== The rack-mount ears or not fully developed and tested
The rackmount ears needs to be developped futher and to be tested. At this moment it's not recommended to place the cluster frame into a 19" rack.

:sectnums!:

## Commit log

2020-11-16 Add electronics dir
    [5V.gbr, BoardOutline.gbr, Bottom.gbr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]
2020-11-20 Update building power_board.adoc
2020-11-23 Add 2.3mm to backplate and fix view to include all components
    [pi_cluster_frame.step]
2020-11-24 Remove backplane shim from components
    [pi_cluster_frame.step]
2020-11-24 Add pi_cluster_frame.f3d so Fusion 360 users have access to sketches as well
    [pi_cluster_frame.f3d]
2020-11-28 Add assemble_led_board.adoc
2020-11-28 Add assemble_led_board.adoc to index.adoc
2020-11-28 Move building_power_board.adoc assemble_power_board.adoc
2020-11-28 Update title assemble_power_board.adoc and index.adoc
2020-11-28 Update title assemble_cluster_hat.adoc
2020-11-28 Add improved RGB_board_solder_helper_tool.step model
    [RGB_board_solder_helper_tool.step]
2020-11-29 Add current_issues.adoc
2020-11-29 Add assemble_front_panel_with_bezel.adoc
2020-11-29 Add assemble_front_panel_with_bezel.adoc to index.adoc
2020-11-30 Add assemble_pi_tray.adoc
2020-11-30 Add assemble_pi_tray.adoc to index.adoc
2020-11-30 Fix wrong image in assemble_pi_tray_doc.adoc
2020-12-01 Update pi_cluster_frame.* make lightpipes a few mm shorter
    [pi_cluster_frame.f3d, pi_cluster_frame.step]
2021-05-01 Update gerber files
    [5V.gbr, BoardOutline.gbr, Bottom.gbr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]
2021-05-02 Add attach back-plane-cover to documentation
2021-05-10 Add schematics
2021-05-10 Add PCB / gerber files
    [Bottom.gbr, BottomMask.gbr, BottomSilk.gbr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]
2021-05-10 Add 3D models and step files
    [Extensible_PI_Cluster.f3d, Extensible_PI_Cluster.step, RGB_board_solder_helper_tool.f3d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]
2021-05-11 Add schematics in pdf format
2021-05-22 Add values to schematic components
2021-05-23 Udate doc with new LED Board
2021-05-23 Add information about printing parts
2021-05-24 Update height backcover
    [Extensible_PI_Cluster.f3d, Extensible_PI_Cluster.step]
2021-05-24 Add section about screwing the frame together
2021-05-24 Update current issues
2021-05-26 Move front-bezel to main component tree
    [Extensible_PI_Cluster.f3d, Extensible_PI_Cluster.step]
2021-05-26 Update 3D print section
2021-06-25 Move I2C power connector for better fit
    [Bottom.gbr, BottomMask.gbr, Through.drl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]
2021-06-25 Add new front module with oled display
    [front_with_oled.f3d, front_with_oled.step]
2021-07-01 Corrected gerber files
    [BoardOutline.gbr, Bottom.gbr, BottomAssy.gbr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]
